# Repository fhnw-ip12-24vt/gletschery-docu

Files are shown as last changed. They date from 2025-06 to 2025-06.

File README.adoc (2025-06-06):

= Produktdokumentation Gletschery

== Einführung

Diese ReadMe-Datei dient als zentraler Steuerpunkt um Sie zu relevanten Informationen zum Produkt Gletschery zu führen.

Dazu gehören die Dokumentation von:

- Softwaredokumentation (SAD)
- Hardware-Dokumentation
- Testdokumentation
- Programmierkonventionen
- Anleitungen

== Softwaredokumentation (SAD)
Die link:software(sad)/sad/[Softwaredokumentation] ist nach den Vorgaben von arc42 erstellt worden (https://arc42.org/) und dokumentiert die Architektur der Softwarelösung.

Die link:software(sad)/system-idee.adoc[System-Idee] enthält das grundlegende Konzept des Projekts.
Es dient als ein Einstieg in die Soft- und Hardware-Dokumentationen.

== Hardwaredokumentation
In der link:hardware/HardwareDokumentation.adoc[Hardwaredokumentation] ist alles erfasst, was zum Bauen des Produkts nötig ist. Dazu gehören:

- *link:hardware/HardwareDokumentation.adoc#_teileliste[Teileliste]*: In der Teileliste sind alle Teile aufgeführt, welche im Produkt verbaut sind.
- *link:hardware/HardwareDokumentation.adoc#_files[Files]*: Beinhaltet alle Dateien, welche für die Erstellung von physischen Bauteilen aus Holz (z.b. Laser) und Plastik (z.b. 3D-Druck) gebraucht wurden.
- *link:hardware/HardwareDokumentation.adoc#_abmessungen[Abmessungen]*: Die Masse für Elemente, welche sich nicht automatisiert herstellen liessen.

Ausserdem enthält die Dokumentation unter anderem Informationen zur link:hardware/HardwareDokumentation.adoc#_wartung[Wartung], link:hardware/HardwareDokumentation.adoc#_erweiterbarkeit[Erweiterbarkeit] und link:hardware/HardwareDokumentation.adoc#_inbetriebnahme[Inbetriebnahme] des Produktes.

== Testdokumentation
Die Testdokumentation zeigt auf, wie geprüft wurde, ob das Produkt den Vorgaben entspricht.

Im link:testing/Admin/Test-Cases-Prüfplan.adoc[Prüfplan] ist festgehalten, welche Vorgaben wie überprüft werden. Einige Vorgaben werden automatisch mit Unit-Test überprüft, andere mit manuellen Tests.

Die Datei link:testing/Admin/Test-Cases-Übersicht.adoc[Test Cases Übersicht] enthält eine Zusammenfassung der durchgeführten Tests.

In der Datei link:testing/Admin/Test-Cases-Namenskonvention.adoc[Namenskonvention] wird aufgeführt auf, welche Beschriftung für die einzelnen Test Cases verwendet wird.

== Programmierkonventionen
Die link:software(sad)/coding_conventions.adoc[Coding Conventions] geben vor, wie der Code geschrieben wird.

== Anleitungen
Die link:software(sad)/Deployment_Anleitung.adoc[Deployment Anleitung] beschreibt im Detail, wie das Deployment durchgeführt werden muss.

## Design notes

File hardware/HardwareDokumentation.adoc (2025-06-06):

= Dokumentation Hardware
:toc-title: Inhalt
:toc: right
:toclevels: 4

== Komponentenübersicht
Die Hardware von Gletschery besteht im Wesentlichen aus:

* den PUI-Elementen, mit welchen der Spieler interagiert,
** Memory-Karten
** Arcade Buttons
** Monitor
* der Elektronik, welche die Funktionalität herstellt,
** Spannungsversorgung
** Zentraleinheit (Raspberry Pi)
** Kamera
** Licht
** diverse Kleinteile
* dem Gehäuse, welches alle Bestandteile vereint
** Holz-Bauteile
** Plexiglasplatte
** Farbe
** diverse Kleinteile

== Teileliste
Die Teileliste führt alle verbauten Bestandteile der Hardware von Gletschery auf.
Sie ist nach den Hauptbestandteilen der Komponentenübersicht gegliedert und gibt Auskunft über die Bezeichnung und die für uns entstandenen Kosten der einzelnen Bauteile.

Für weitere Details zu den einzelnen Komponenten folgen Sie den Links auf die Komponenten.

=== PUI

|===
|Komponenten |Bezeichnung |Beschaffung |Kosten

| Memory-Karten (24x)
| Eigenfertigung
| 3D-Druck
| 0.-

| xref:Komponenten/Arcade-Buttons.adoc[Arcade Buttons (3x)]
| Arcade Push Button illuminated (purecrea)
| Einkauf
| 15.70

| xref:Komponenten/Monitor.adoc[Monitor]
| PM-14 (verbatim)
| Einkauf
| 79.-

|===

=== Elektronik

|===
|Komponenten |Bezeichnung |Beschaffung |Kosten

| xref:Komponenten/Netzteil.adoc[Netzteil]
| TXN 75-105 (Traco Power)
| FHNW
| 0.-

| Hauptschalter
| Hauptschalter
| FHNW
| 0.-

| zentrale Steuereinheit
| Pi 5 (Raspberry)
| FHNW
| 0.-

| Shield
| Shield auf 40-Pin Header Pi (FHNW)
| FHNW
| 0.-

| xref:Komponenten/Kamera.adoc[Kamera]
| Camera Module 3 Wide (Raspberry)
| Einkauf
| 45.70

| xref:Komponenten/Kamera-Kabel.adoc[Kamera-Kabel]
| RASP CAM FPC 50 CSI (Raspberry)
| Einkauf
| 8.70

| LED-Band
| 5V LED-Band
| FHNW
| 0.-

| xref:Komponenten/LED-Steuerung.adoc[LED-Steuerung]
| Output Expander EM-03 (Pixelblaze)
| FHNW
| 0.-

| diverse Kabel
| Custom Eigenfertigung
| FHNW
| 0.-

|===

=== Gehäuse

|===
|Komponenten |Bezeichnung |Beschaffung |Kosten

| Holzgehäuse
| Custom Eigenfertigung Holz-Bauteile
| FHNW / Einkauf
| 19.45

| Kamera-Halter
| Eigenfertigung
| 3D-Druck
| 0.-

| Spielfläche
| Plexiglasplatte
| Einkauf
| 11.95

| Farbe
| FS Premium Buntlack S012.04
| Einkauf
| 15.95

| diverse Kleinteile
| Schrauben, Stifte, Scharniere
| eigene Werkstatt
| 0.-

|===

Die Gesamtkosten dieser Teileliste belaufen sich auf 196.45 CHF.

Dabei ist zu beachten, dass viele Bauteile kostenfrei von der FHNW zur Verfügung gestellt wurden und ein 1:1 Nachbau mit identischen Komponenten die Kosten um einiges erhöhen würden.

== Anschlussschemata

Die Schemata zeigen eine Übersicht über das Gesamtsystem der Spannungsversorgung und Signalverbindungen.

Einzelheiten auf welchen Steckplätzen welche Kabel angeschlossen sind sind unter den jeweiligen Komponenten zu finden:

* xref:Komponenten/Arcade-Buttons.adoc[Arcade Buttons (3x)]
* xref:Komponenten/LED-Steuerung.adoc[LED-Steuerung]

=== Spannungsversorgung

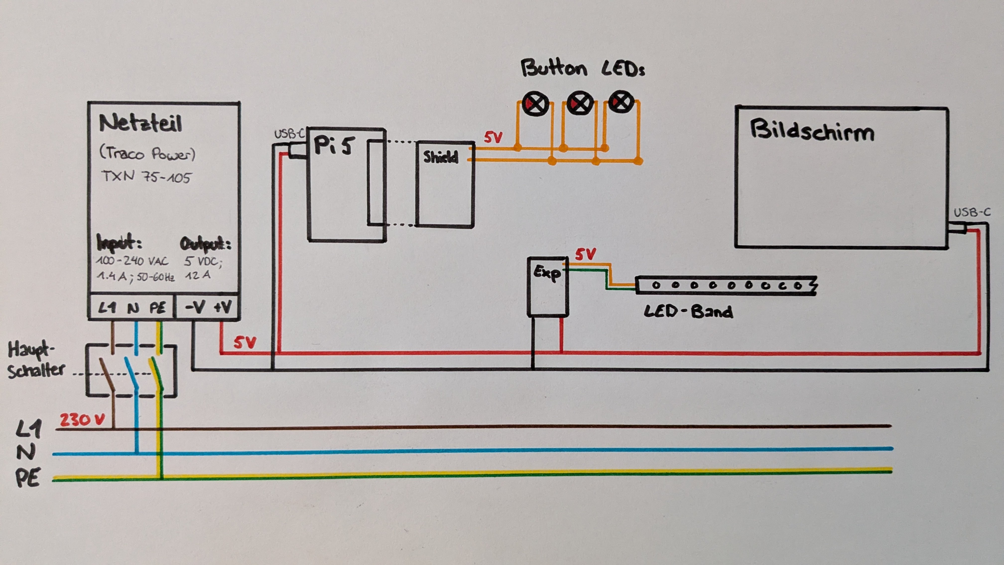
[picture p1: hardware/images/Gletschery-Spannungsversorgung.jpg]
ahhhhlternativtext


=== Signalverbindungen

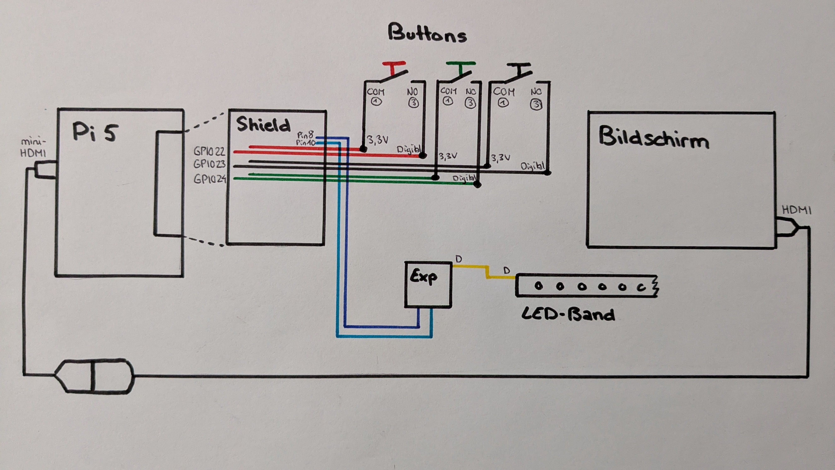
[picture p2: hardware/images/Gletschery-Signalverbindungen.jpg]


== Files

=== STP - Gletschery Modell

* xref:3D-Files/GletscheryModell.step[GletscheryModell.step]
* Pfad: hardware/Files/GletscheryModell.step
* Das GletscheryModell im STEP Format beinhaltet alle Bauteile des Gehäuses

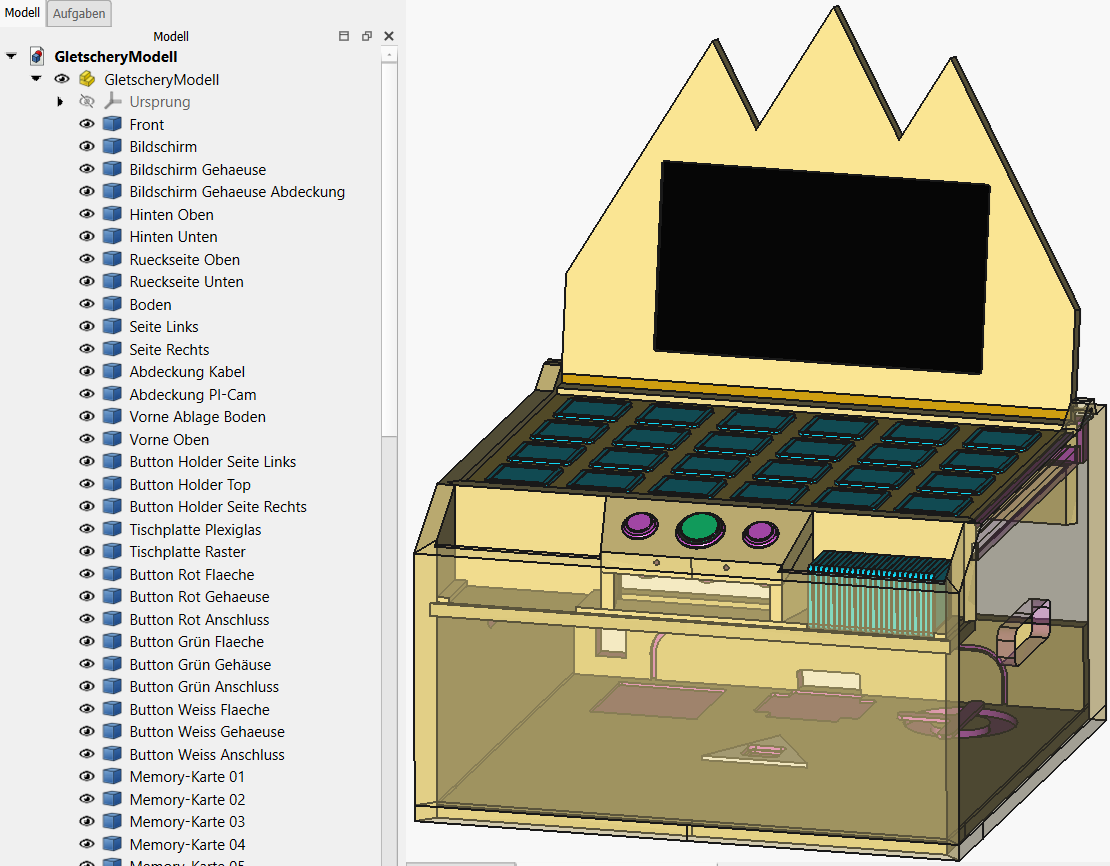
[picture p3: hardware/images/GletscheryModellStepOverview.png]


* Sollten Sie kein Programm haben um STP-/STEP-Dateien zu öffnen, empfehlen wir FreeCAD, ein kostenloses Open-Source CAD: https://www.freecad.org/
* Durch hovern über die Bauteile werden einzelne Komponenten hervorgehoben:

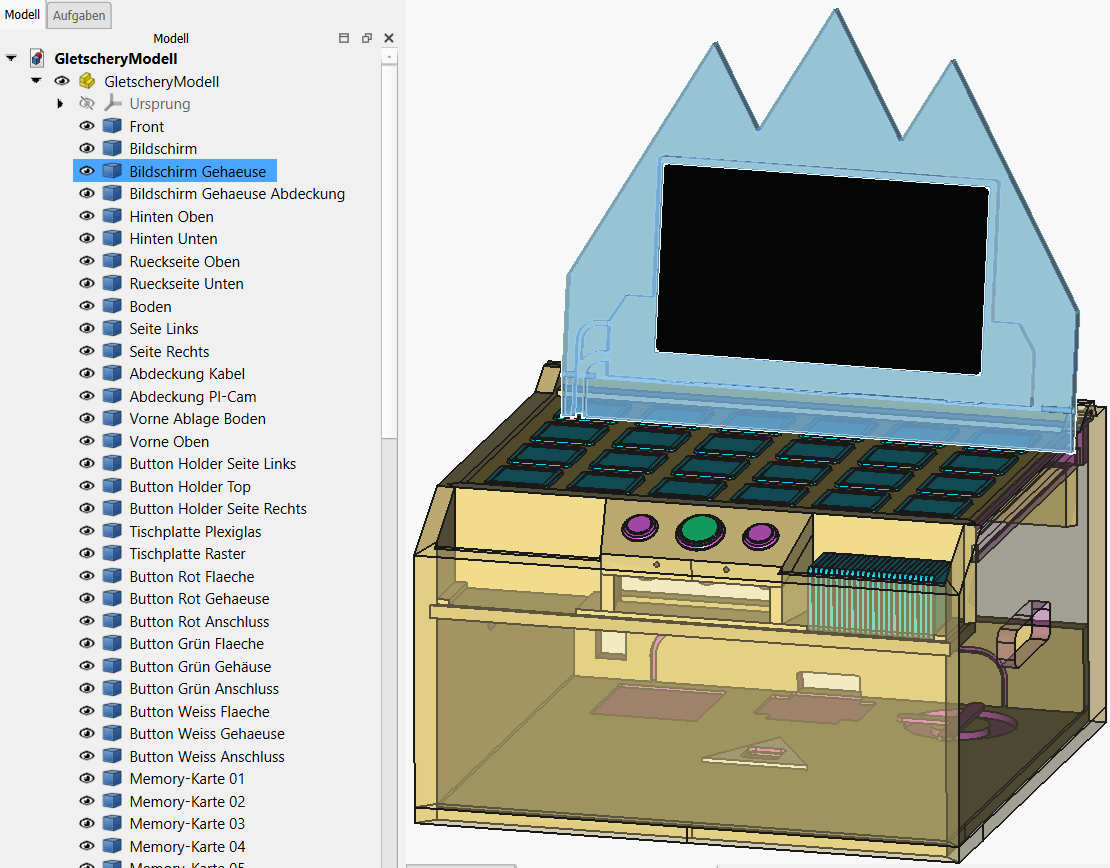
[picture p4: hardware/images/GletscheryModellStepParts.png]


[#_stl__3d_druck_modelle]
=== STL - 3D Druck Modelle

* Alle 3D-Druckmodelle wurden mit einem Original Prusa MK3.9 0.4 nozzle Drucker hergestellt
* Als Filament wurde Generic PLA hellblau verwendet
* Als Referenz für weitere Druckeinstellungen dient das folgende PrusaSlicer Projekt:
** xref:3D-Files/memory-cards-v5.3mf[memory-cards-v5.3mf]
** Pfad: hardware/Files/memory-cards-v5.3mf

==== Memory-Karten

* xref:3D-Files/memory-cards-v4 60x60x5_R5.stl[memory-cards-v4 60x60x5_R5.stl]
* Pfad: hardware/Files/memory-cards-v4 60x60x5_R5.stl

==== Kamera-Aufnahme

* xref:3D-Files/PI-CamHolderV2.stl[PI-CamHolderV2.stl]
* Pfad: hardware/Files/PI-CamHolderV2.stl

=== Abmessungen

* Aussenabmessungen Gletschery geöffnet: 519 x 500 x 656
* Aussenabmessungen Gletschery geschlossen: 519 x 500 x 317

Alle Masse in mm.

Bei Bedarf können die Masse jedes beliebigen Bauteils aus der STEP-Datei xref:3D-Files/GletscheryModell.step[GletscheryModell.step] in einem beliebigen CAD ausgelesen werden.

== Inbetriebnahme

Nach dem initialen Deployment der Software auf dem Raspberry Pi inklusive Autostart (welches vom Projektteam übernommen wird) ist die Inbetriebnahme des Produktes ganz einfach:

Schritte für die Inbetriebnahme:

* Anschliessen Stromkabel an Netz
** öffnen Sie die Rückseite des Gehäuses (durch öffnen der zwei Scharniere) und entnehmen Sie das mitgelieferte lose Stromkabel
** Stecken Sie das Stromkabel an der Rückseite (rechts unten) an und verbinden Sie die andere Seite mit Ihrem Stromnetz.
* Betätigen Sie den Hauptschalter
** Der Hauptschalter befindet sich gleich über dem Anschluss des Stromkabels welches Sie gerade verbunden haben
* Autostart
** Der Bildschirm startet sich nach einschalten des Stroms automatisch.
** Der Pi fährt sich ebenfalls automatisch hoch und startet das Spiel.
* Willkommen im Hauptmenü
** Nach einer kurzen Ladephase landen Sie bequem im Hauptmenü des Spiels, von wo aus Sie verschiedene Möglichkeiten haben:
*** ein neues Spiel starten
*** Sprache auswählen
*** Spielanleitung betrachten
*** eine Diashow der verwendeten Fotos ansehen
*** Die Credits lesen

Abschalten des Systems:

* Das System kann einfach über den Hauptschalter abgeschaltet werden

== Wartung

[#_plexiglas_auswechseln]
=== Plexiglas auswechseln

Das Plexiglas kann zur Rückseite hin herausgezogen werden.Im aufgestellten Zustand sind jedoch das Bildschirmgehäuse und deren Verkabelung im Weg.

Folgende vorbereitenden Schritte sind notwendig um das Plexiglas auszuwechseln:

* Zuklappen des Bildschirmgehäuses
* 3 Schrauben auf der Rückseite des Bildschirmgehäuses lösen, sodass die Abdeckung abgenommen werden kann.
* Strom- und HDMI-Kabel am Bildschirm entfernen und beachten, dass diese unterhalb der Nut für das Glas liegen.
* Um besseren Zugang zu haben wird empfohlen, das gesamte Oberteil abzunehmen: dazu entfernen Sie die beiden Stifte auf den Seiten (am Bestem mittels Kneif- oder Gripzange), danach kann das Oberteil einfach abgenommen werden.
* Entfernen Sie nun alle Karten sowie das Raster von der Spielfläche

Folgende Schritte werden zum Auswechseln empfohlen:

* Tragen Sie Sicherheitshandschuhe
* Öffnen Sie die Rückklappe und greifen sie mit einer Hand hindurch um die Plexiglasplatte von unten (nahe den Buttons) etwas in Richtung der Rückseite zu ziehen.
* Greifen Sie das Glas von oben mittig am entstandenen Spalt und drücken Sie es gleichmässig zur Rückseite hinaus
* Sobald das Glas über die Rückseite herausragt, ziehen Sie es von hinten hinaus.

Einschieben des neuen Glases

* Tipp: Schutzfolie nur an den Rändern etwas entfernen, sodass die Fläche beim Einschieben geschützt bleibt.
* Von der Rückseite her das Glas gleichmässig einschieben
* Wenn das Glas an der Vorderseite ansteht, durch die Rückklappe von unten mit einer Hand etwas anheben und mit der anderen Druck von Hinten geben, bis es schön in der Nut sitzt.
* Das Glas sitzt korrekt, sobald es auf der Rückseite vollständig bündig mit der Abdeckung ist.

Oberteil wieder anbringen:

* Legen Sie das Oberteil flach in Position
* Schieben Sie einen Stift von der Seite ein (durch leichtes Bewegen des Oberteils merken Sie, wann der Stift gefasst hat)
* Setzen Sie den Stift auf der gegenüberliegenden Seite
* Das Oberteil ist nun wieder befestigt
* Schliessen Sie Strom- und HDMI-Kabel an und legen Sie die Kabel in die entsprechenden Kanäle
* Schrauben Sie die Abdeckung wieder an.

=== Memory-Karten

Die Memory-Karten bestehen aus einem 3D gedruckten Körper, einem Gletscherfoto auf einer Seite und einem (dem Foto zugeordneten) QR-Code auf der anderen Seite.

Die Fotos/QR-Codes sind auf normales Papier gedruckt, laminiert und mit einem starken doppelseitigen Klebeband auf den Kartenkörper geklebt.

==== Karten-Körper

Es werden 8 Ersatzkarten mitgeliefert. Um selbständig Karten zu drucken, finden Sie weiter oben in diesem Dokument einige Infos, STL-Files sowie ein Druckprojekt, welches Sie verwenden können ->
xref:HardwareDokumentation.adoc#_stl__3d_druck_modelle[STL Modelle]

==== Gletscher-Fotos

Diese Doku beinhaltet 2 PDFs mit druckfertigen Fotos in der richtigen Grösse für die Karten. Einmal mit und einmal ohne Namen. Sollten Sie Anpassungen machen wollen, können Sie gerne das .docx als Vorlage nehmen:

* xref:Documents/eigene/All-Gletscher-Images 46mm.pdf[]
* xref:Documents/eigene/All-Gletscher-Images 46mm mit Label.pdf[]
* xref:Documents/eigene/All-Gletscher-Images 46mm.docx[]

==== QR-Codes

Druckfertige QR-Codes in der richtigen Grösse finden Sie in folgenden Dokumenten:

* xref:Documents/eigene/All-QR-Codes Table 42mm.pdf[]
* xref:Documents/eigene/All-QR-Codes Table 42mm.docx[]

==== Zuordnung

Die Zuordnung der Codes zu den Gletschern, sowie den angezeigten Texten findet in einem JSON-File statt. Infos dazu finden Sie in der

* xref:../software(sad)/Deployment_Anleitung.adoc#_daten[Deployment Anleitung unter Daten]

Die standalone Texte mit den Fakten finden Sie ansonsten in folgenden Dokumenten:

* xref:Documents/eigene/Fakten Gletscher DE.docx[]
* xref:Documents/eigene/Fakten Gletscher EN.docx[]
* xref:Documents/eigene/Fakten Gletscher FR.docx[]

=== Arcade-Buttons

Sollten Sie die Buttons auswechseln müssen, so ist dies möglich, aber nicht ganz einfach :)

Details zu den Buttons (Link zum Händler und elektrische Anschlüsse) finden Sie hier: xref:Komponenten/Arcade-Buttons.adoc[Arcade-Buttons]

* Folgen Sie der Anleitung xref:HardwareDokumentation.adoc#_plexiglas_auswechseln[Plexiglas auswechseln] bis zu dem Schritt an welchem Sie das Glas entfernt haben, um besseren Zugang zu haben.
* Nun können sie die Unterseite des auszuwechselnden Buttons (dort wo die Kabel angeschlossen sind) ein wenig gegen den Uhrzeigersinn drehen (dabei brauchen Sie initial etwas mehr Kraft als Sie erwarten würden, Sie merken jedoch schnell wenn es sich löst)
** (das Unterteil wird, beim Zusammenbau, zuerst in einer L-Nut gerade nach oben zusammengesteckt und dann etwas im Uhrzeigersinn gedreht, wodurch die Komponenten zusammenhalten - diesen Schritt gilt es umgekehrt zu machen)
** Sollte sich der gesamte Button Drehen, so geben Sie von der Oberseite Gegen-Druck auf den schwarzen Rand (aber nicht auf die Druckfläche - dies verhindert ein Lösen!)
* Nun kann das Unterteil des Buttons gerade nach unten herausgezogen werden. Die Kabelschuhe wurden für den besseren Halt gelötet.
** Sollten Sie diesen Teil auswechseln müssen so muss das Lot gelöst werden
** Markieren Sie sich unbedingt die Kabel auf der Button-Seite bevor Sie diese lösen, sodass Sie beim Ersetzen wissen, welche Anschlüsse wohin kommen. Die Anschlüsse auf Seite Pi/Shield sind entsprechend beschriftet.
* Um den Button / Oberen Teil zu entfernen, lösen Sie die Plastik-Mutter auf der Innenseite (nach Entfernen des Unterteils)
** Danach können Sie den gesamten Button von unten am Plastikgewinde gerade nach oben herausdrücken
** (Das Plastikgewinde dient nur dem Anziehen der Mutter, das Gehäuse selbst ist keine Gewinde- sondern eine Durchgangsbohrung)

== Erweiterbarkeit

Ideen zur Weiterentwicklung / Ausbau:

=== Spielfläche

* Weitere Raster um Anzahl Memory-Karten zu lenken
* Oder Sie versuchen das Raster wegzulassen, um die Technik sichtbarer zu machen. (wir hatten ohne Raster begonnen uns jedoch wegen folgenden Problemen für eines entschieden)
** mehr Probleme mit dem Auto-Fokus der Kamera auf entfernte Decken-Elemente
** weniger zuverlässige Erkennung der QR-Codes bei schräg liegenden Karten

=== Beleuchtung

* Die verbauten LEDs sind individuell steuerbar und RGB fähig
** Sie können das Innere in verschiedenen Farben oder Leuchtsequenzen zu neuem Leben erwecken
** Wir hatten beispielsweise während einiger Zeit bei einem richtigen Paar grün und bei einem falschen Paar oder Scan-Misserfolg rot angezeigt was richtig gut aussah (später jedoch wieder weggelassen, wir die Bildnachbearbeitung auf helles weisses Licht optimiert hatten)

=== Inhalt

* Auswechseln von Motiven und Texten ist ziemlich einfach in einem JSON-File möglich. Seien Sie kreativ.

=== Software

* Wie wäre es mit weiteren Spielmodi: zB einem Singleplayer oder Ranglisten-Modus

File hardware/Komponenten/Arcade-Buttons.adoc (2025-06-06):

= Arcade Buttons

|===
|Key specifications |details

|Hersteller
|purecrea

|Model
|Arcade Push Button Illuminated

|Spannungsversorgung LED
|5-12V

|Preis
|33mm: CHF 4.90; 45mm: 5.90

|Produktlink
|https://www.bastelgarage.ch/illuminated-arcade-button-33mm-red[Link zu 33mm Red auf bastelgarage.ch]

https://www.bastelgarage.ch/components/switch-button/arcade-push-button-illuminated-33mm-white[Link zu 33mm White auf bastelgarage.ch]

https://www.bastelgarage.ch/components/switch-button/arcade-push-button-lit-45mm-green[Link zu 45mm Green auf bastelgarage.ch]
|===

== Anschlüsse Signalverbindungen

image::../images/Arcade Buttons Signal Anschluesse.png[]

== Anschlüsse Stromversorgung

Die LED's der Buttons haben einen eigenen Stromkreis. Sie wurden von uns so zusammengebaut, dass der Anschluss auf der roten Seite dem 5V+, derjenige auf der schwarzen Seite dem 5V- auf dem Netzteil entspricht

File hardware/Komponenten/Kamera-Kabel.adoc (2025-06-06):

= Kamera-Kabel

|===
|Key specifications |details

|Model
|RASP CAM FPC 50

|connectors
|1x CSI - 1x CSI

|Length
|50mm

|Preis
|CHF 8.70

|Produktlink
|https://www.digitec.ch/en/s1/product/raspberry-pi-rasp-cam-fpc-50-raspberry-pi-camera-cable-1x-csi-1x-csi-050-m-development-board-accesso-40089192[Link zu Produkt auf digitec.ch]
|===

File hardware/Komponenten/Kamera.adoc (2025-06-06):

= Kamera

|===
|Key specifications |details

|Model
|Camera Module 3 Wide

|Sensor
|Sony IMX708

|Resolution
|11.9 megapixels

|Horizontal/vertical
|4608 × 2592 pixels

|Output
|RAW10

|Autofocus system
|Phase Detection Autofocus

|Cable connector
|15 × 1mm FPC

|Compliance
|FCC 47 CFR Part 15, Subpart B, Class B Digital Device
Electromagnetic Compatibility Directive (EMC) 2014/30/EU
Restriction of Hazardous Substances (RoHS) Directive
2011/65/EU

|Preis
|CHF 45.70

|weitere Dokumente
|xref:../Documents/camera-module-3-product-brief.pdf[Pi cameras product brief]

|Produktlink
|https://www.digitec.ch/en/s1/product/raspberry-pi-camera-module-3-wide-angle-120-development-board-accessories-24041966[Link zu Produkt auf digitec.ch]
|===

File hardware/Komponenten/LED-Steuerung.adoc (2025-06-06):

= LED-Steuerung

|===
|Key specifications |details

| Hersteller
| Pixelblaze

|Model
|Output Expander EM-03

|weitere Dokumente
|https://electromage.com/docs/output-expander[Output Expander Documentation]

|Produktlink
|https://shop.electromage.com/products/pixelblaze-output-expander-serial-to-8x-ws2812-apa102-driver[Link zum Produkt des Herstellers]
|===

Der Output Expander ist für die Steuerung und Spannungsversorgung des LED-Bands zuständig.

* Die Inputs 5V und GND sind direkt am Netzteil angeschlossen.
* Die Inputs DAT und CLK sind mit den GPIO-Pins 8 und 10 des Pi verbunden.
* Die Outputs 5V, GND und Data sind auf Reihe 0 mit den entsprechenden, gleich bezeichneten, Counter-Parts am LED-Band verbunden.

== Anschlüsse

image::../images/LED-Steuerung Anschluesse.jpg[]

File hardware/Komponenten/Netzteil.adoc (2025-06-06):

= Netzteil

|===
|Key specifications |details

| Hersteller
| Traco Power

|Model
|TXN 75-105

|Input
|100 - 240 VAC; 50/60 HZ

|Output
|5 VDC;

|weitere Dokumente
|xref:../Documents/txn75_datasheet.pdf[Technical data sheet]

|Produktlink
|https://www.tracopower.com/model/txn-75-105[Link zum Produkt des Herstellers]
|===

Das Netzteil versorgt unser gesamtes System mit Spannung.

Direkt an das Netzteil angeschlossen und mit 5V DC-Spannung versorgt werden:

* der Raspberry Pi
* der Bildschirm
* das LED-Band

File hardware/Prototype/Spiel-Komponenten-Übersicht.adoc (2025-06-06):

= Dokumentation Spiel-Komponenten

*Inhalt Spiel-Komponenten*

- [x] 1.1 Tisch
- [x] 2.1 Memory-Karten

'''
== 1.1 Tisch

Prototyp Komponenten:

|===
|Komponenten |Beschreibung

|xref:Tisch/MDF-Box.adoc[MDF-Box]

11.12.2024

|Prototype-Box welche Tischplatte sowie alle Hardware-Komponenten aufnehmen kann.

|xref:Tisch/Tischplatte.adoc[Tischplatte]

12.12.2024

|Durchsichtiges Spielfeld aus Glas oder Plexiglas.

|xref:Tisch/PiCam-Halterung.adoc[PI-CamHolder-v1]

17.12.2024

|Element, welches auf dem "Boden" der Prototyp-Box befestigt wird, um die PI-Kamera zu positionieren und befestigen.

|Steckerleiste
|Dient dem Stromanschluss von Pi, Monitor und LEDs

|LED-Band
|Dient der Beleuchtung des Innenraums der Box

|===

== 2.1 Memory-Karten

Tests/Prototypes:

|===
|Testlauf |Abklärung

|xref:MemoryCards/Memory-Cards-v1.adoc[Memory-Karten Test 1]

25.11.2024

|Abklärungen 3D-Konstruktion und 3D-Druck

|xref:MemoryCards/Memory-Cards-v2.adoc[Memory-Karten Test 2]

26.11.2024

|Ausprobieren verschiedener Formen und Grössen für UX-Testing

|xref:MemoryCards/Memory-Cards-v3.adoc[Memory-Karten Test 3]

27.11.2024

|Analyse & Verbesserung der Druckqualität und verschiedene Kartendicken für UX-Testing

|xref:MemoryCards/Memory-Cards-v4.adoc[Memory-Karten Test 4]

29.11.2024

|Verschiedene Formen in gleicher Druckqualität zur besseren Vergleichbarkeit. Genug in der Anzahl um für Prototype im Spiel zu verwenden.

|===

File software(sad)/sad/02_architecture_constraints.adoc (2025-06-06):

[[section-architecture-constraints]]
== Randbedingungen
=== Technische Einschränkungen
.Performance
Raspberry-Pi bietet eine limitierte Performance, welche bei der Entwicklung und Umsetzung beachtet werden muss. Zudem läuft auf dem Raspberry-Pi eine Linux Distribution, was bei der Umsetzung ebenso beachtet werden muss, da dies bei Aspekten wie Pfade von Ressourcen (z.B. Bildern) wichtig ist.

.Lichtverhältnisse
Dadurch, dass unser Produkt mit einer Kamera arbeitet, welche von unten QR-Codes scannt, können die Lichtverhältnisse im Raum und in der Box zu  Problemen führen. Sollte zu viel oder zu wenig Licht auf die Kameralinse treffen, kann dies zur schlechten Erkennung von QR-Codes führen.

.QR-Code Erkennung
Neben schlechten Lichtverhältnissen können weitere Faktoren, wie beispielsweise der Zustand der Memorykarten, die Erkennung des QR-Codes beeinflussen.

.Java
Ebenfalls wurde von der Programmleitung festgelegt, dass Java als Programmiersprache verwendet werden muss.

==== Git-Versionierung
Die Versionierung der Dokumentation und des Codes erfolgt gemäss den Vorgaben der Projektleitung mit Git und GitLab.

.Richtlinien
Damit die Dokumentation und der Code stets übersichtlich bleibt, werden Richtlinien festgelegt, die von den Teammitgliedern befolgt werden.

.Namenskonvention
Um die Übersicht zu behalten, welcher Branch wofür erstellt wurde, wurde eine Namenkonvention definiert, nach welcher gearbeitet wird.

- **Code-Repository**
** Name des Branches: "Feature-[NAME]"
-> (z.B. Feature-Scanner)
- **Dokumentation**
** Name des Branches: [Rolle] -> (z.B. software-architect)

.Erklärung
Für jede Änderung im Code oder in der Dokumentation wird ein neuer Branch erstellt, der den definierten Namenskonventionen entspricht. Nach der Bearbeitung wird der Branch-Stand gepusht und schliesslich mit dem Main-Branch zusammengeführt. Der verwendete Branch wird nach dem Zusammenführen gelöscht.

Im Gegensatz zur Code-Dokumentation wird das Mergen von Code im Code-Repository mit dem Main-Branch von anderen Teammitgliedern überprüft. Dies dient dazu, potenzielle Gefährdungen des bestehenden Codes und den damit verbundenen Aufwand zur Behebung von Problemen zu vermeiden. Die Überprüfung des Codes erfolgt durch den Software Developer oder Software Architect des Teams.

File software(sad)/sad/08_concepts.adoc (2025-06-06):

[[section-concepts]]
== Querschnittliche Konzepte
=== Fachliche Konzepte

==== Bewusstseinsbildung
Das Spiel dient nicht nur der Unterhaltung, sondern verfolgt ein pädagogisches Ziel: Die Vermittlung von Wissen über Gletscher, deren Rückgang und die klimatischen Zusammenhänge. Dieses Ziel ist systemweit relevant und beeinflusst die inhaltliche Gestaltung der Karten, die Auswahl der Bilder sowie die Textbausteine der GUI.

==== Memory
Das Spiel basiert auf dem bekannten Memory-Prinzip. Zwei Karten mit gleichem Bild oder thematischem Zusammenhang müssen gefunden werden. Eine Übereinstimmung triggert die Anzeige weiterführender Informationen auf dem Bildschirm. Diese Spielmechanik bildet das Grundmodell für alle Interaktionen.

=== User Experience (UX)

==== Feedback-Verhalten
Spielrückmeldungen erfolgen multimodal:

* Visuell über Display (Text und Farbwechsel)
* Namen der Gletscher und Bilder auf den physischen Karten

==== Barrierefreiheit
Das Spiel ist für Jugendliche ab 13 Jahren konzipiert. Farben und Kontraste wurden für gute Lesbarkeit gewählt. Steuerung erfolgt hardwareseitig über drei klar gekennzeichnete Tasten (Farbcodierung: Rot, Grün, Weiss).

==== Steuerung
Alle Spielaktionen werden über drei physische Buttons ausgelöst:

* Rot = Spiel beenden / zurück
* Grün = Bestätigen / Scannen
* Weiss = Navigation

Die Knöpfe sind bewusst mechanisch um einfache Bedienung zu garantieren.

=== Sicherheitskonzepte

==== Scan-Bildverarbeitung
Bilder von der Kamera werden lokal und flüchtig verarbeitet:

* Es erfolgt zwar eine Speicherung von Bilddaten, diese werden aber überschrieben und nach dem Beenden einer Runde gelöscht.
* Verarbeitung direkt bei Erstellung, via FFMPEG.
* Nur extrahierter QR-Text wird weiterverarbeitet.

==== Hardwareschutz
* Das System ist vollständig in einer verschlossenen Holzkiste untergebracht.

=== Architektur- und Entwurfsmuster

==== MVC
Die Java-Anwendung folgt der **MVC** Architektur

* **Model**: Spielzustand, Kartendaten
* **View**: Anzeige auf dem Bildschirm
* **Controller**: Programm logik

==== Threads und zusätzliche Prozesse
Die Anwendung ist multi-threaded:

* **Thread 1**: Gletschery Game-Loop an sich (dauerhaft aktiv)
* **Thread 2**: Scannen und Lesen nach QR-Codes(nur während Spiel aktiv)
* **Prozess**: Zusätzlich wird ein Bash-Script ausgeführt welches jede Sekunde ein neues aktuelles Foto abspeichert.

=== Unter der Haube

==== GPIO und UART
* Drei Buttons sind an dedizierte GPIO-Pins angeschlossen.
* Eine LED wird über den UART (seriell) angesteuert über vorgeschalteten Mikrocontroller.
* Alle GPIOs werden über PI4J verwaltet.

==== Kameraeinbindung
* Kamera: PiCam Modul 4, angebunden über CSI-Port
* Zugriff: Libcamera und FFMPEG in Java
* Verarbeitung: Live-Frame-Erfassung,
* Performance: 1 fps

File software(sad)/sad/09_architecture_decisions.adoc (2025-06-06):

[[section-design-decisions]]
== Architekturentscheidungen
=== MVC

Für unser Projekt wurde aus verschiedenen Gründen entschieden eine MVC Architektur zu verwenden.
Im Folgenden werden die wichtigsten Gründe erwähnt.

1. **Wartbarkeit:**
* Dadurch, dass unser Projekt notfalls von einer externen Partei gewartet werden muss, ist es von Vorteil, wenn die Komponenten so wenige Abhängigkeiten wie möglich voneinander haben.
2. **Separation of Concerns (Trennung von Verantwortlichkeiten):**
* Die Aufteilung der einzelnen Komponenten führen dazu, dass die einzelnen Komponenten getestet werden können, ohne die Logik zu beeinflussen.
3. **Testbarkeit:**
* Unit-Tests können für Models und Controller einfacher geschrieben werden.
4. **User-Interface:**
* Dadurch, dass unser Spiel verschiedene Screens haben wird, welche die gleichen Daten anzeigen, ist eine MVC Architektur von Vorteil.

=== Klassendiagramm

Um die Struktur des Codes festzulegen, wurde ein Klassendiagramm erstellt. **Jede Schicht der MVC Architektur wird in einem eigenen Package** zusammengefasst.
Der Grund dafür ist die Sicherstellung, dass **keine Schichten übergreifende Relationen** entstehen.

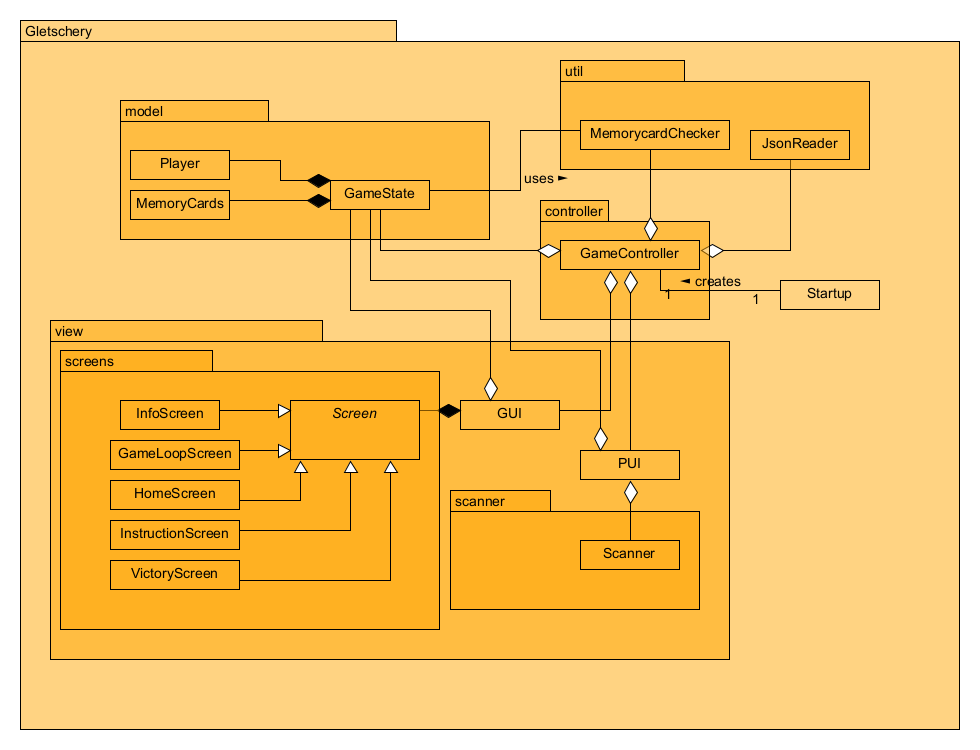
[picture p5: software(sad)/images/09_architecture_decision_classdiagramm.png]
Klassendiagramm


=== Architecture Decisions

[cols="1,3" options="header"]
|===
|Name |Decision
|Gletscherbilder Speicher Ort| Die Gletscherbilder werden auf dem Raspberry-PI unter "/home/pi/Pictures" gespeichert, um einfach austauschbar zu sein.
|Scan Image Speicher Ort| Das Scan-Image wird während des Spiels hier abgelegt "/home/pi/Pictures".
|Löschen des letzten Scan Images| Sobald das Spiel beendet wurde soll das letzte Bild gelöscht werden um gegen keine Datenschutzrichtlinien zu verstossen.
|Json speicher Location| Das Json wird auf dem Raspberry-PI unter "/home/pi/Documents" gespeichert.
|Json aufbau | Das Json ist wie folgt aufgebaut
|Karten ID's | Die IDs der Karten sind ein String, welcher so aufgebaut ist: <Paar-ID><CardIdentifier>. Als CardIdentifier wird jeweils A oder B verwendet. z.B. "00A"
|Paar-ID| Die Paar-ID besteht immer aus 2 Zeichen
|Paar-ID Start| Die Vergabe der ID's startet bei 00
|===

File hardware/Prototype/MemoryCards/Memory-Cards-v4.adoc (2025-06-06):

= Memory-Karten Test 4

*Datum:* Fr, 29.11.2024

*Testziel:*

- [x] Verschiedene Dicken und Formen für engere Auswahl UX-Tests
- [x] Analyse & Verbesserungspotenzial der Druckqualität

'''

*Testdetails:*

Konstruktion Details

- Grösse: 60x60
- Eckform: Fasen und verschiedene Radien
- je zwei verschiedene Dicken in 6mm und 5mm
- alle Karten haben oben und unten eine Vertiefung von 1 um Bild/QR-Code zu platzieren
- alle scharfen Aussenkanten haben eine Fase von 0.5
- Files: xref:3D_Files/memory-cards-v4 60x60x5_F5.stl[memory-cards-v4 60x60x5_F5.stl] ; xref:3D_Files/memory-cards-v4 60x60x5_R5.stl[memory-cards-v4 60x60x5_R5.stl] ; xref:3D_Files/memory-cards-v4 60x60x5_R6.stl[memory-cards-v4 60x60x5_R6.stl] ; xref:3D_Files/memory-cards-v4 60x60x5_R7.stl[memory-cards-v4 60x60x5_R7.stl] ; xref:3D_Files/memory-cards-v4 60x60x6_F5.stl[memory-cards-v4 60x60x6_F5.stl] ; xref:3D_Files/memory-cards-v4 60x60x6_R5.stl[memory-cards-v4 60x60x6_R5.stl] ; xref:3D_Files/memory-cards-v4 60x60x6_R6.stl[memory-cards-v4 60x60x6_R6.stl] ; xref:3D_Files/memory-cards-v4 60x60x6_R7.stl[memory-cards-v4 60x60x6_R7.stl]

3D-Druck Details

- Anzahl Karten: 8
- Grössen: 60x60x6 und 60x60x5
- Druckeinstellungen: Voreinstellungen modifiziert: PLA; 0.4 Nozzle; 0.2 Speed; glattePlatte; Perimeter: 10mm; Deckenfüllmuster: Ausgerichtet Geradlinig; Randbreite: 3mm; Infill: 15%, Füllmuster: Gitternetz; generiere Stützmaterial + Stützen automatische generieren;

'''

*Ergebnis:*

- Oberfläche Rand mit neuer Strategie (Perimeter 10mm) nicht so glatt wie mit alter Strategie, dafür gleichmässiger. An einigen Ecken sind Bahnen etwas auseinandergezogen.
- Tiefere Aussparung auf Ober- und Unterseite gut gelungen
- Zusammen mit Test 1, 2 und 3 haben wir nun viele verschiedene Formen und Grössen um Userfeedback einzuholen um das Kartendesign zu finalisieren
- Wir haben nun genug gedruckte Karten um ein Testspiel mit halbem Umfang zu machen (12 Memory Karten, 6 Paare)

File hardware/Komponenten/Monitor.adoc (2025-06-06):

= Monitor

|===
|Key specifications |details

|Model
|Verbatim PM-14

|Monitor type
|PC Monitor, Portable Monitor

|Display size
|14"

|Display resolution
|1920x1080

|Screen technologie
|LCD

|Refresh rate
|60 Hz

|Video connections
|HDMI (1x)

|USB ports
|USB-A, USB-C

|Monitor equipment
|Integrated loudspeakers, Integrated USB hub

|Preis
|CHF 79.- (Aktion)

|weitere Dokumente
|xref:../Documents/Produktdatenblatt PM-14.pdf[Technical data sheet]

|Produktlink
|https://www.digitec.ch/en/s1/product/verbatim-pm-14-1920-x-1080-pixels-14-monitor-24552684?tagIds=77-624[Link zu Produkt auf digitec.ch]
|===

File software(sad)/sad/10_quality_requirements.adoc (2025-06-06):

[[section-quality-scenarios]]
== Qualitätsanforderungen
.Einleitung
Diese Anforderungen dienen als Grundlage für die Architektur und unterstützen dabei, die Erwartungen der Stakeholder klar zu erfassen und gezielt umzusetzen.

=== Qualitätsbaum
Der Qualitätsbaum stellt alle Qualitätsanforderungen unseres Produktes übersichtlich dar. Wir haben uns dabei vor allem auf die Qualitätsziele **Leistungseffizienz**, **Benutzerfreundlichkeit** und **Wartbarkeit** fokussiert. Diese Qualitätsziele basieren auf den Vorgaben und Anforderungen des Kunden Primeo Energie.

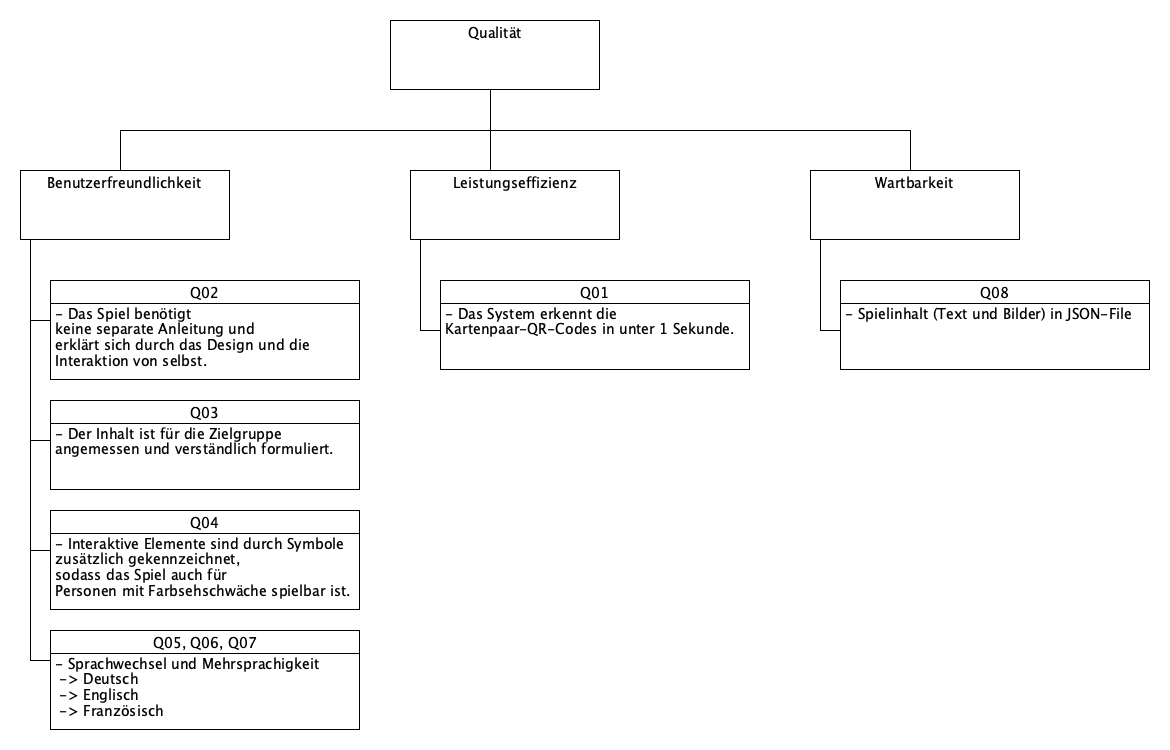
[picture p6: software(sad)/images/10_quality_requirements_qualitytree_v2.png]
Qualitätsbaum


=== Qualitätsanforderungen im Detail

[cols="1,2,4", options="header"]
|===
| Anforderung | Qualitätsanforderung | Beschreibung

| Q01
| Leistungseffizienz
| Das System erkennt die Kartenpaar-QR-Codes in unter 1 Sekunde.

| Q02
| Benutzerfreundlichkeit
| Das Spiel benötigt keine separate Anleitung und erklärt sich durch das Design und die Interaktion von selbst.

| Q03
| Benutzerfreundlichkeit
| Der Inhalt ist für die Zielgruppe angemessen und verständlich formuliert.

| Q04
| Benutzerfreundlichkeit
| Interaktive Elemente sind durch Symbole zusätzlich gekennzeichnet, sodass das Spiel auch für Personen mit Farbsehschwäche spielbar ist.

| Q05
| Benutzerfreundlichkeit
| Das Spiel ist in mehreren Sprachen verfügbar und kann vor dem Start des Spiels ausgewählt werden.

| Q06
| Benutzerfreundlichkeit
| Die Menüstruktur ist in allen Sprachen konsistent und übersichtlich.

| Q07
| Benutzerfreundlichkeit
| Alle Inhalte sind in den Sprachen Deutsch, Englisch und Französisch verfügbar.

| Q08
| Wartbarkeit
| Die Spielinhalte (Texte und Bilder) sind in einer externen JSON-Datei abgelegt und können ohne Änderung des Quellcodes angepasst werden.
|===

[.small]
-> *QS-01* prüft *Q01 (Leistungseffizienz)*

-> *QS-02* prüft *Q02 (Benutzerfreundlichkeit – selbsterklärende Bedienung)*

-> *QS-03* prüft *Q03 (Benutzerfreundlichkeit – Angemessenheit der Sprache im Spiel)*

-> *QS-04* prüft *Q04 (Benutzerfreundlichkeit – Barrierefreiheit)*

-> *QS-05* prüft *Q05 (Benutzerfreundlichkeit – Sprachwahl)*

-> *QS-06* prüft *Q06 (Benutzerfreundlichkeit – konsistente Menüstruktur)*

-> *QS-07* prüft *Q07 (Benutzerfreundlichkeit – Inhalte in mehreren Sprachen anzeigen)*

-> *QS-08* prüft *Q08 (Wartbarkeit – Anpassungen an der JSON-Datei)*

=== Qualitätsszenarien

[cols="1,2,2,2,2", options="header"]
|===
| ID | Stimulus | Umgebung | Reaktion des Systems | Erfolgskriterium

| QS-01
| Ein Spieler deckt eine Karte bei schwachen Lichtverhältnissen auf.
| Umgebungslicht ohne direkte Beleuchtung
| Das System erkennt den QR-Code innerhalb einer Sekunde.
| QR-Code wird in 95 % der Fälle korrekt erkannt

| QS-02
| Ein Benutzer startet das Spiel zum ersten Mal.
| Kein Vorwissen über Spiel oder Steuerung
| Der Spieler findet sich im Menü zurecht und startet das Spiel ohne Hilfe.
| 90 % der Testpersonen benötigen keine Erklärung

| QS-03
| Ein Spieler liest den Infotext über einen Gletscher im Spiel
| Spiel läuft in deutscher Sprache
| Die Texte sind altersgerecht und leicht verständlich formuliert.
| Mindestens 90 % der Testpersonen (entspricht 9 von 10) verstehen die Inhalte ohne Rückfragen.

| QS-04
| Ein farbenblinder Spieler nutzt das System.
| Spiel läuft im Normalbetrieb
| Alle interaktiven Elemente sind auch durch Symbole eindeutig erkennbar.
| Der Spieler kann ohne Probleme durch das Spiel navigieren.

| QS-05
| Eine Spielerin möchte das Spiel auf Französisch nutzen.
| Sprache im Startmenü auf Französisch gestellt
| Alle Menüs und Texte erscheinen in korrekter französischer Übersetzung.
| Keine fehlenden oder unübersetzten Texte sind zu sehen

| QS-06
| Ein Spieler wechselt zwischen Deutsch, Englisch und Französisch.
| Menüführung in den verschiedenen Sprachen (Deutsch, Englisch und Französisch) jeweils ausgewählt.
| Menüstruktur bleibt in allen Sprachen identisch aufgebaut.
| Kein Unterschied in Navigationsstruktur oder Position von Buttons

| QS-07
| Ein Schüler spielt das Spiel auf Englisch.
| Englische Sprache im Startmenü ausgewählt
| Alle Inhalte (Texte und Buttons) erscheinen korrekt übersetzt.
| Alle Inhalte erscheinen in der gewünschten Sprache

| QS-08
| Neue Inhalte (Bilder, Texte) sollen eingepflegt werden.
| Ein Entwickler aktualisiert die JSON-Datei mit neuen Inhalten.
| Die neuen Inhalte werden beim nächsten Spielstart korrekt angezeigt.
| Die Änderungen erfolgen ohne Codeanpassung und das Spiel startet fehlerfrei.
|===

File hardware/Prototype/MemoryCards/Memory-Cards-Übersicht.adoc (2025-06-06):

= Memory Card Übersicht

*Datum:* Mi, 05.03.2025

*Inhalt*

Diese Übersicht dient der Dokumentation der QR-Codes und ihrer eindeutigen Zuordnung zu einer bestimmten Memorykarte.

'''
*Zuweisung*

|===
|QR-Code |Bild |Pfad

|01A |XX |
|01B |XX |
|02A |XX |
|02B |XX |
|03A |XX |
|03B |XX |
|04A |XX |
|04B |XX |
|05A |XX |
|05B |XX |
|06A |XX |
|06B |XX |
|07A |XX |
|07B |XX |
|08A |XX |
|08B |XX |
|09A |XX |
|09B |XX |
|10A |XX |
|10B |XX |
|11A |XX |
|11B |XX |
|12A |XX |
|12B |XX |

|===

Die Identifikationsnummer der QR-Codes setzt sich aus einer einzigartigen Zahl und dem Buchstaben 'A' oder 'B' zusammen. Der Buchstabe kennzeichnet dabei das historische bzw. das neuzeitliche Bild des Kartenpaares.

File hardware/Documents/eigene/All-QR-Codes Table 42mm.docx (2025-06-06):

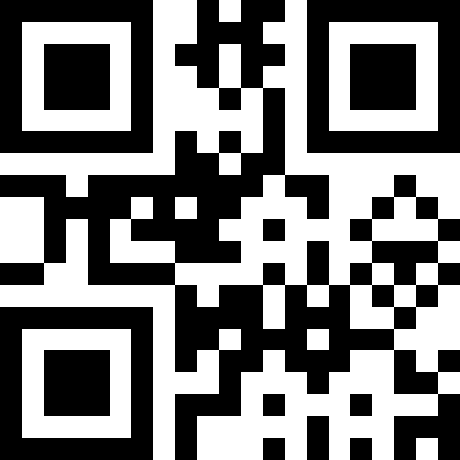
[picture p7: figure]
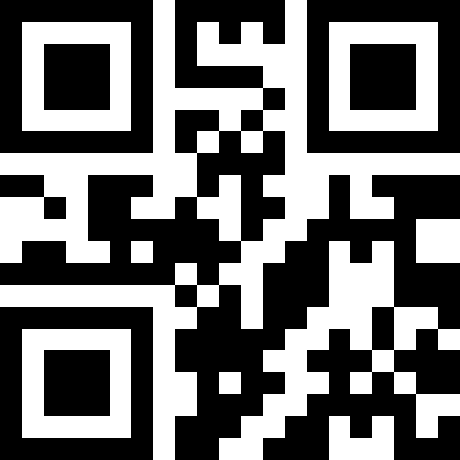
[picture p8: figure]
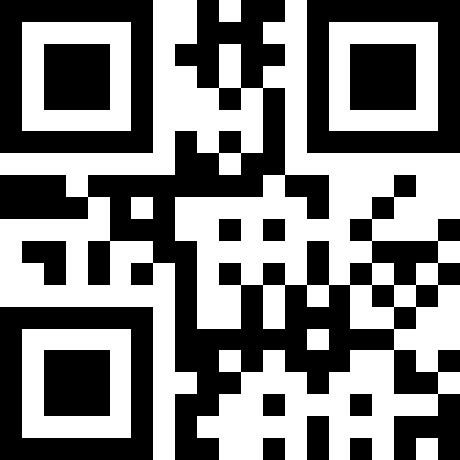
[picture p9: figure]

00A | 00B | 01A

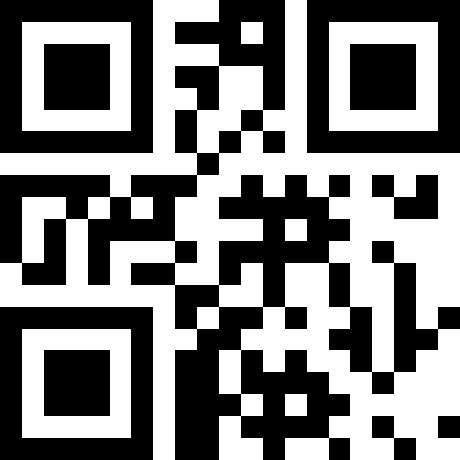
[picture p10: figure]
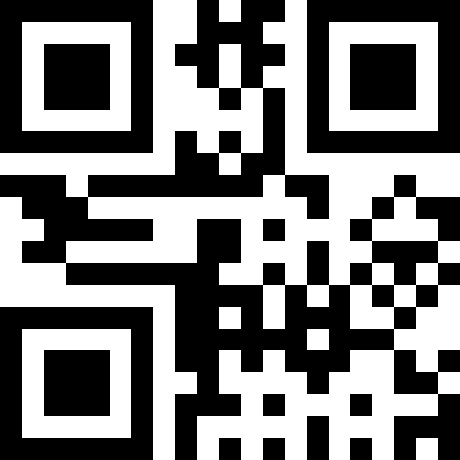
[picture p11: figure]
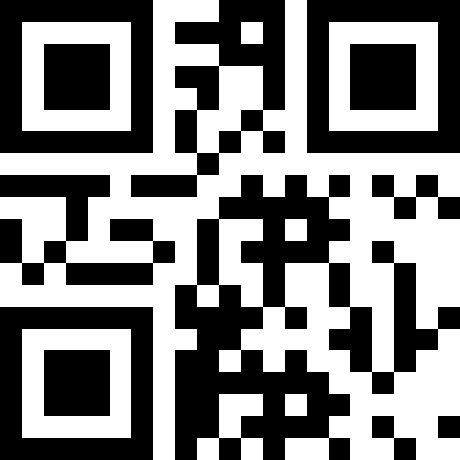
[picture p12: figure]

01B | 02A | 02B

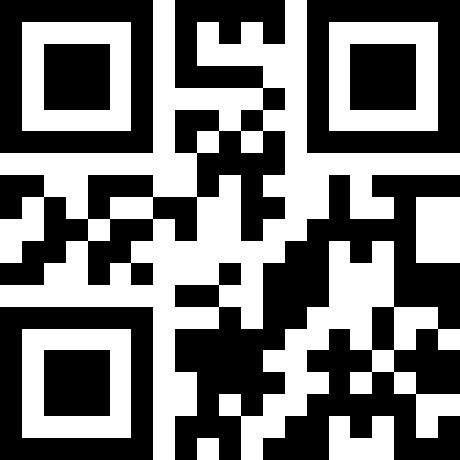
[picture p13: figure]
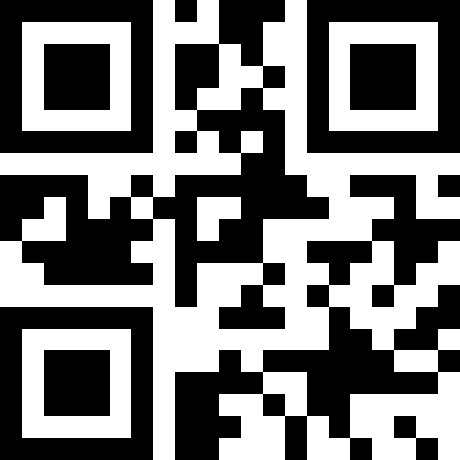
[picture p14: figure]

03A | 03B | 04A

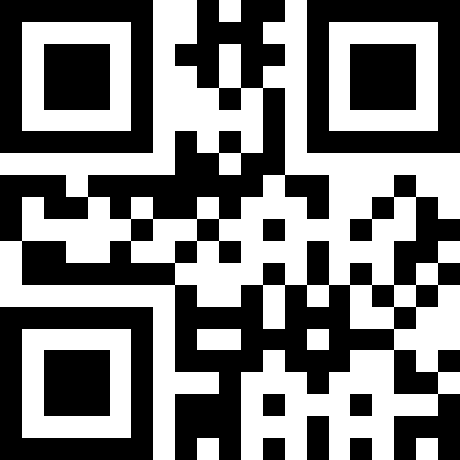
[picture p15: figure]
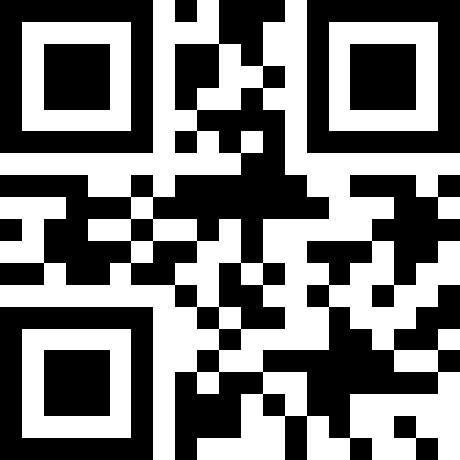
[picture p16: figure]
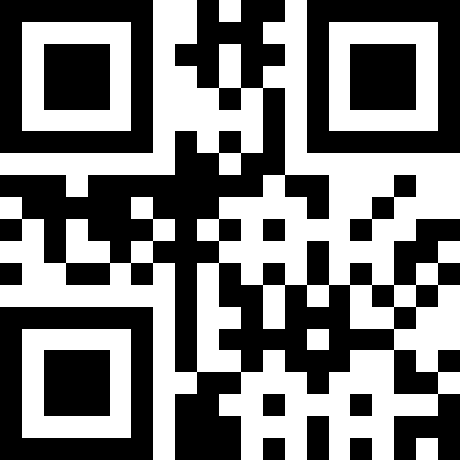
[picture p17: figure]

04B | 05A | 05B

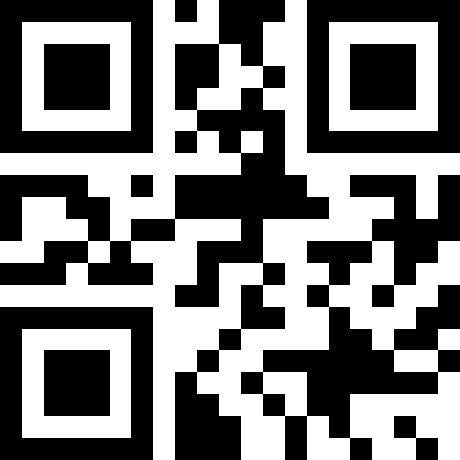
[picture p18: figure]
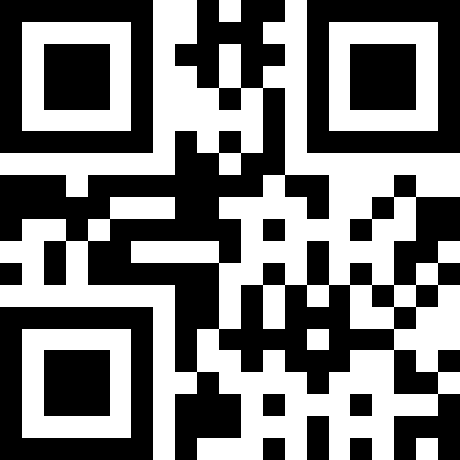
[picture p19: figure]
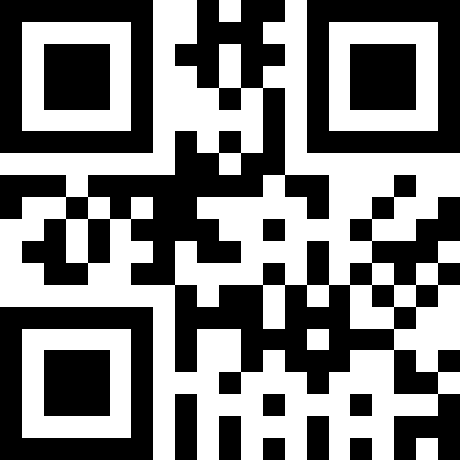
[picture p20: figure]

06A | 06B | 07A

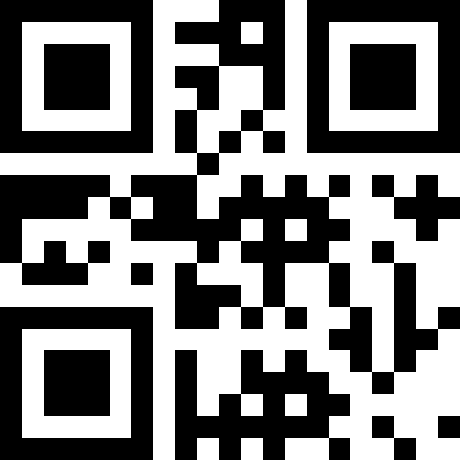
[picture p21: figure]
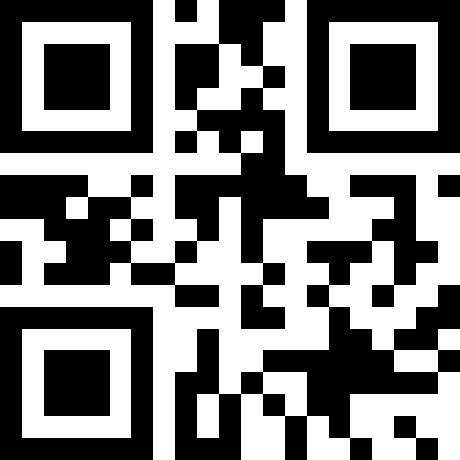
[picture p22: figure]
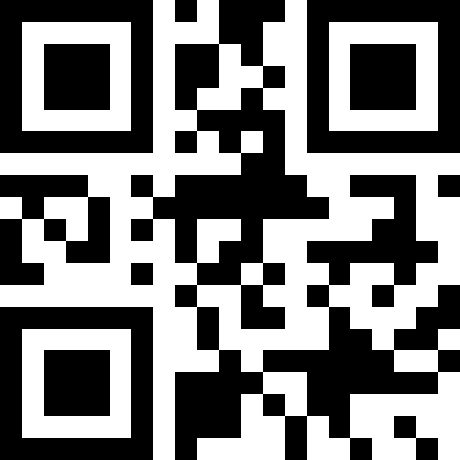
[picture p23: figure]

07B | 08A | 08B

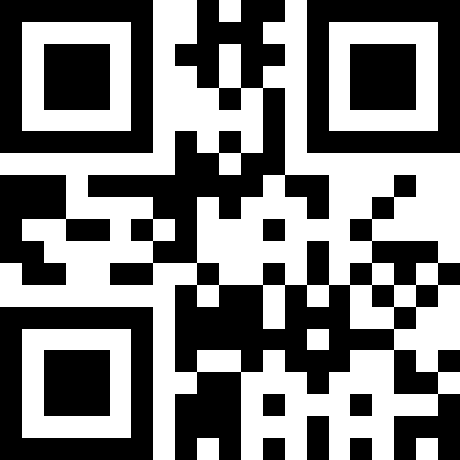
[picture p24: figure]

09A | 09B | 10A


10B | 11A | 11B


12A | 12B

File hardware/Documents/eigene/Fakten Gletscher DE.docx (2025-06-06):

Persgletscher, GR

Früher war der Gletscher fest mit dem Morteratschgletscher verbunden. Durch die Schmelze sind die beiden Gletscher momentan nicht mehr miteinander verbunden.

Tiefengletscher, UR

Der Tiefengletscher ist ein Talgletscher in den Urner Alpen. Das Schmelzwasser des Gletschers fliesst über den Sidelenbach in die Reuss, dann in die Aare, wo es schliesslich in den Rhein mündet.

Pizolgletscher, GR

Der Pizolgletscher zerfiel aufgrund der grossen Hitze im Jahr 2018 in mehrere, einzelne Teile. Er gilt als einer der ersten Schweizer Gletscher, der vollständig schmelzen wird.

Tschiervagletscher, GR

Der Tschiervagletscher war bis 1944 mit dem Roseggletscher im Tal Roseg verbunden. Der Rückzug beider Gletscher führte dann zur Bildung des "Lej da Vadret".

Gornergletscher, VS

Der Gornergletscher erstreckt sich über etwa 12 Kilometer, wobei er an seine dicksten Stellen eine Eisstärke von über 350 Meter erreicht. Seit 1850 ist er bereits über 3 km zurückgegangen.

Aletschgletscher, VS

Der grösste Gletscher der Alpen und doch sagen Prognosen voraus, dass er bis zum Ende 21. Jahrhundert fast komplett verschwinden könnte.

Riedgletscher, VS

Vor langer Zeit wurde das Wasser des Gletschers über alte Wasserleitungen namens «Suonen» bis zu den Gemeinden St. Nikolaus und Grächen transportiert, um dort die Wiesen zu bewässern.

Fieschergletscher, VS

Der Fieschergletscher ist mit 14 km einer der längsten Gletscher der Alpen und hat seit 1850 bereits über 3 km an Länge verloren.

Roseggletscher, GR

Durch das Schmelzen des Gletschers hat sich ein neuer Gletschersee gebildet, der weiterwächst, während das Eis schwindet.

Trientgletscher, VS

Aufgrund seiner Steile schmilzt der Gletscher schneller als andere, somit zeigt er früher als andere Gletscher, wie sich das Klima auf die Alpen auswirkt.

Rhonegletscher, VS

Seit einigen Jahren werden Teile des Gletschers mit weissem Fliessstoff abgedeckt, um die Schmelze zu verlangsamen.

Triftgletscher, BE

Durch die starke Schmelze hat sich in den 1990er der Triftsee gebildet und wächst seitdem jedes Jahr weiter an.


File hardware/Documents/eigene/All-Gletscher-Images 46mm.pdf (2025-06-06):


00A | 00B | 01A
01B | 02A | 02B
03A | 03B | 04A
04B | 05A | 05B


06A | 06B | 07A
07B | 08A | 08B
09A | 09B | 10A
10B | 11A | 11B

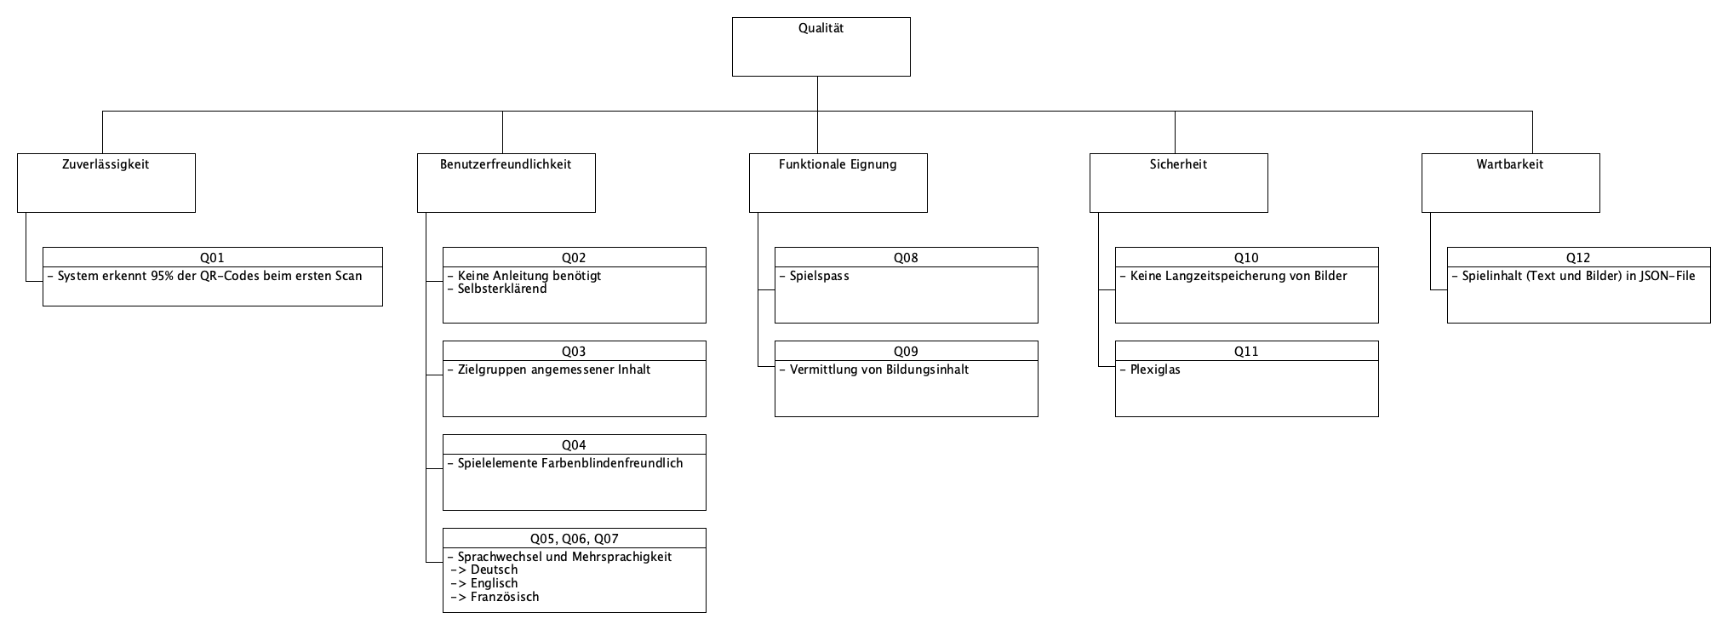
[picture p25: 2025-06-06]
software(sad)/images/10_quality_requirements_qualitytree.png

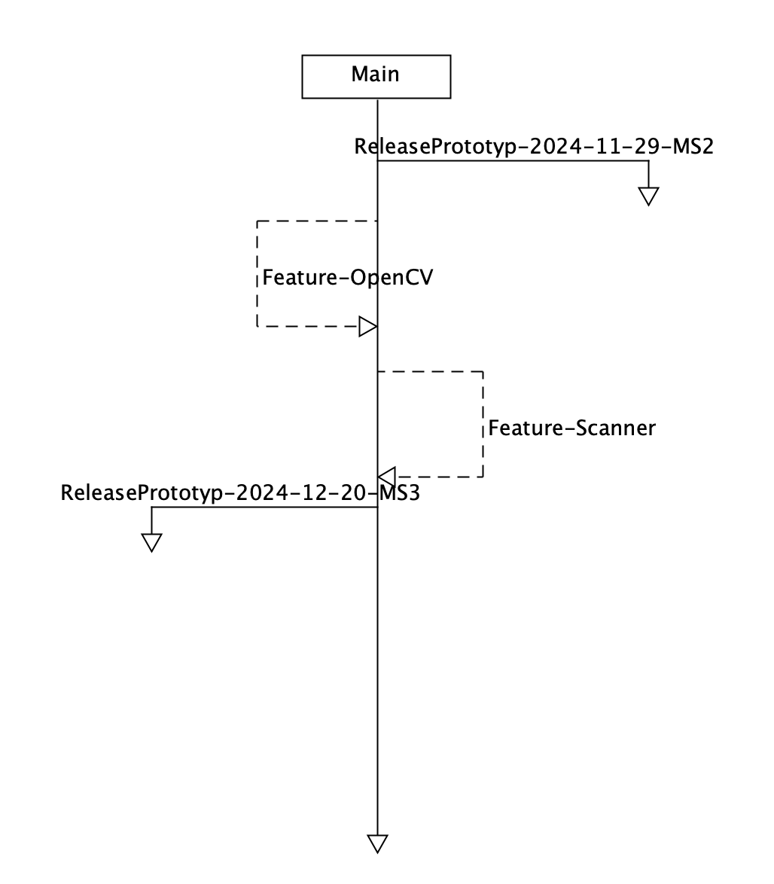
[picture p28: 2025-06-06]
software(sad)/images/02-architecture-constraints-git-branches.png

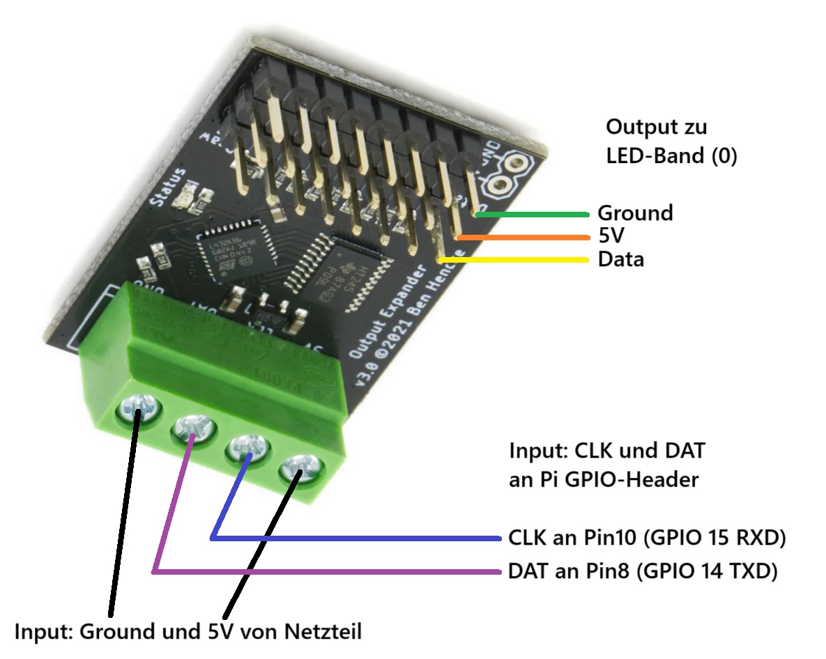
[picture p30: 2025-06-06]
hardware/images/LED-Steuerung Anschluesse.jpg

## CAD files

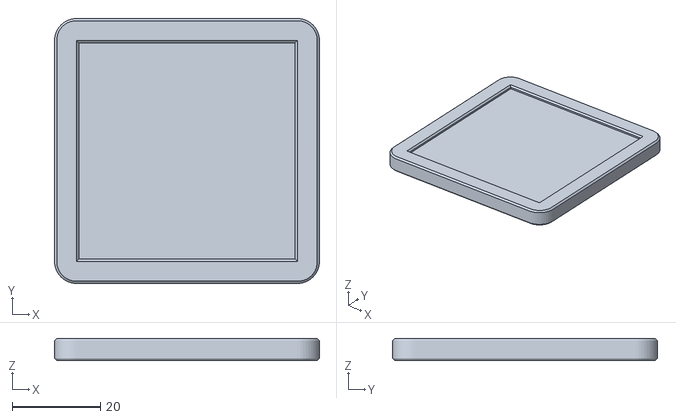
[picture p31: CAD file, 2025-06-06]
hardware/3D-Files/memory-cards-v4 60x60x5_R5.stl
60.0 x 60.0 x 5.00

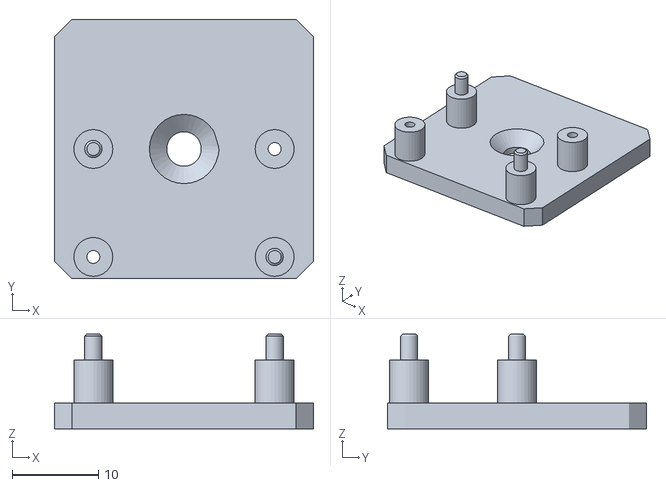
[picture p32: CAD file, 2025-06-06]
hardware/Prototype/Tisch/3D_Files/PI-CamHolder.stl
30.0 x 30.0 x 11.0

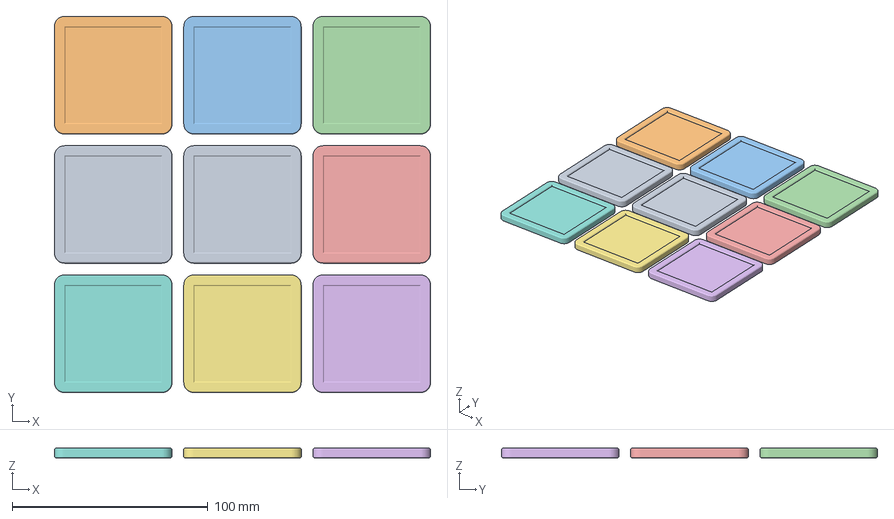
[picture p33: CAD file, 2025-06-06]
hardware/3D-Files/memory-cards-v5.3mf
192.0 x 192.0 x 5.00 mm

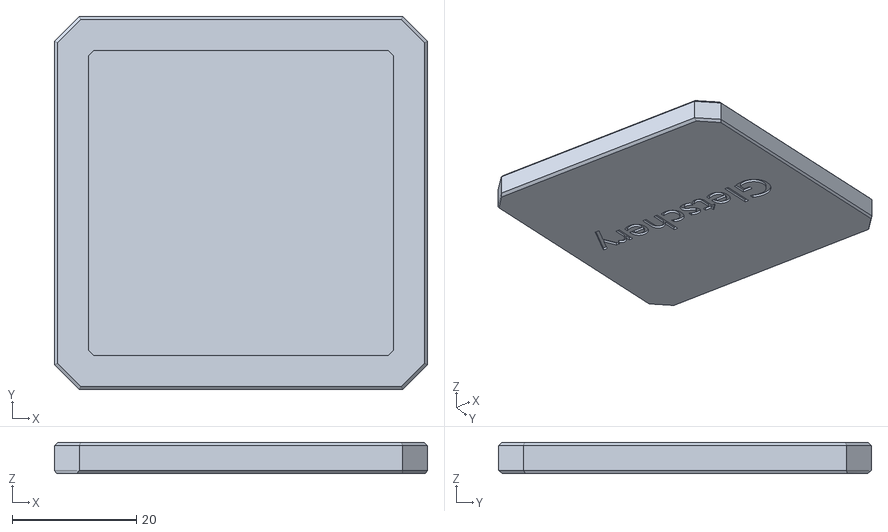
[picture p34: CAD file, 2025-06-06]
hardware/Prototype/MemoryCards/3D_Files/memory-cards-v1.stl
60.0 x 60.0 x 5.00

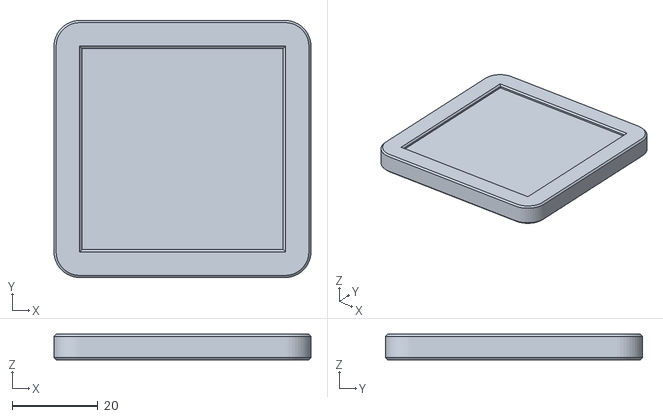
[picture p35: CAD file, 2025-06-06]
hardware/Prototype/MemoryCards/3D_Files/memory-cards-v4 60x60x6_R6.stl
60.0 x 60.0 x 6.00

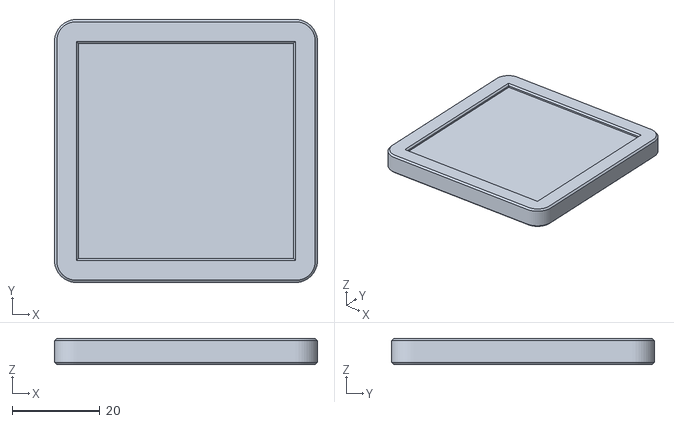
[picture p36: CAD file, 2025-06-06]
hardware/Prototype/MemoryCards/3D_Files/memory-cards-v4 60x60x6_R5.stl
60.0 x 60.0 x 6.00

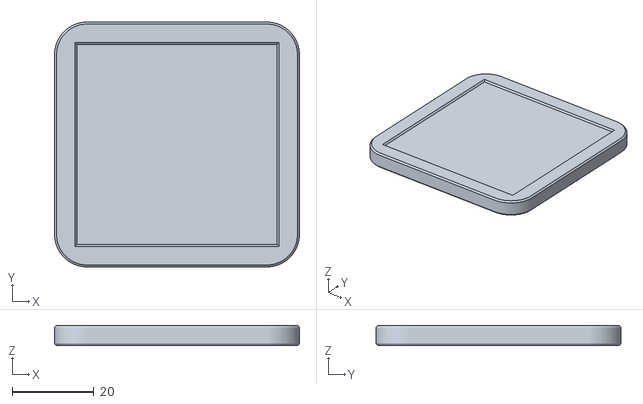
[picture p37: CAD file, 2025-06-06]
hardware/Prototype/MemoryCards/3D_Files/memory-cards-v2 60x60x5 radius.stl
60.0 x 60.0 x 5.00

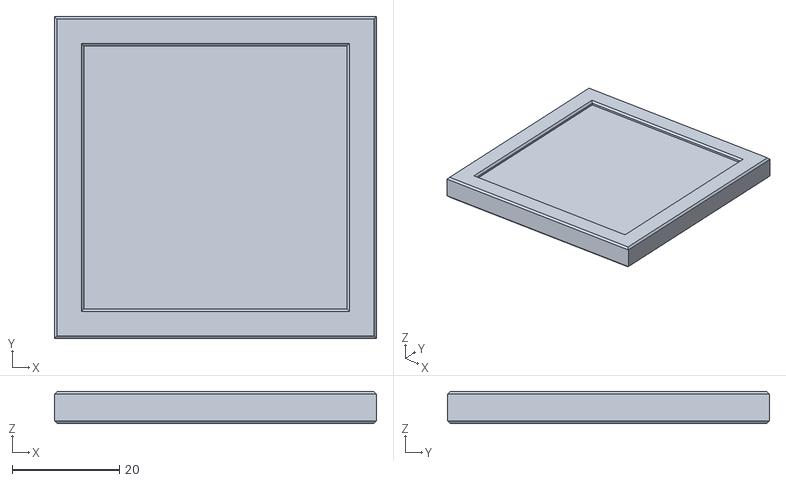
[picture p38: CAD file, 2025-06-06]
hardware/Prototype/MemoryCards/3D_Files/memory-cards-v3 60x60x6.stl
60.0 x 60.0 x 6.00

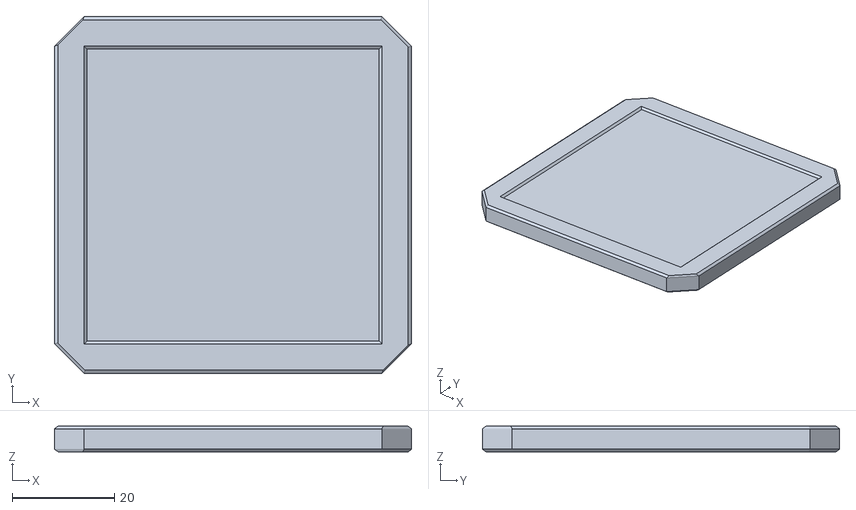
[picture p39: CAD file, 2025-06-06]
hardware/Prototype/MemoryCards/3D_Files/memory-cards-v2 70x70x5.stl
70.0 x 70.0 x 5.00

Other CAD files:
hardware/3D-Files/PI-CamHolderV2.stl
hardware/Prototype/MemoryCards/3D_Files/memory-cards-v4 60x60x5_R7.stl
hardware/Prototype/MemoryCards/3D_Files/memory-cards-v4 60x60x6_F5.stl
hardware/Prototype/MemoryCards/3D_Files/memory-cards-v4 60x60x5_R6.stl
hardware/Prototype/MemoryCards/3D_Files/memory-cards-v2 60x60x5.stl
hardware/Prototype/MemoryCards/3D_Files/memory-cards-v4 60x60x6_R7.stl
hardware/Prototype/MemoryCards/3D_Files/memory-cards-v4 60x60x5_F5.stl
hardware/Prototype/MemoryCards/3D_Files/memory-cards-v2 70x70x5 radius.stl
hardware/Prototype/MemoryCards/3D_Files/memory-cards-v3 60x60x7.stl

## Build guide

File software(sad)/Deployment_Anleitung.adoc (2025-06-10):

= Anleitung: Gletschery

== Depolyment

=== GitHub

* Repository-Link: https://github.com/fhnw-ip12-24vt/gletschery-docu/tree/main:[Link]

Laden Sie den Ordner files aus dem angegebenen GitHub-Repository herunter und speichern Sie die darin enthaltenen dateien auf dem Raspberry Pi an den beschriebenen Positionen.

=== Dateien

Die folgenden Datei- oder Dateigruppen sind an die jeweils angegebenen Verzeichnisse des primären Benutzers zu verschieben:

==== Gletscher-Bilder

Kopieren nach:

`~/Pictures/gletscherImages`

==== Icons und restliche Bilder

Kopieren nach:

`~/Pictures/generalImages`

==== JSON-Datei

Kopieren nach:

`~/Documents`

==== Bash-Skript: makeImage

Kopieren nach:

`~/Documents`

=== Autostart

Gletschery fungiert wie ein plug & play Spiel, das heisst,
wenn es am Strom angesteckt ist und eingeschaltet ist, bootet das Spiel automatisch.
Dies wird mithilfe eines Startskripts und Cron realisiert:

1. Erstelle folgendes Directory:
`/home/pi/scripts/`

2. Kopiere `startScript.sh` in `/home/pi/scripts/`

3. Gebe folgenden Befehl im Terminal ein: `crontab -e`
und wähle einen präferierten Text-Editor.

4. füge folgende Zeile hinzu: `@reboot sleep 10 && bash /home/pi/scripts/startScript.sh`

5. starte den cron service, indem folgende Befehle im Terminal eingegeben werden:

** `sudo systemctl daemon-reload`

** `sudo systemctl enable cron.service`

** `sudo systemctl start cron.service`

falls der Cron job scheduler bearbeitet werden muss, kann man dies mit dem folgenden command in bash tun:

`crontab -e`

Nun sollte Gletschery starten, wenn der Rasperry Pi eingeschaltet wird.

Wenn Gletschery geschlossen wird, wenn es am laufen ist (z.B. durch Alt+F4), muss man zuerst alle Instanzen von Gletschery beenden, bevor man es wieder starten kann.

Dies kann man entweder manuell machen mit Hilfe des folgendem bash commands:

`sudo pkill -f Gletschery`

oder man kann den command in einem executable bash script kopieren, und somit entweder bei Bedarf den Skript ausführen,
oder den script in eine benutzeridentifizierte Applikation auf den Rasperry Pi verwandeln.

Ein Tutorial wie das realisiert werden kann, findet man hier:

https://www.youtube.com/watch?v=Y9_3DlFqc1Q

[#_daten]
== Daten

Wenn daten angepasst werden sollen passiert dies Grundsätzlich über das JSON.Unten werden die Häufigsten fälle kurz beschrieben.

=== Gletscher hinzufügen oder entfernen
Um einen Gletscher hinzuzufügen muss im JSON unter dem Punkt pairs einen Neuen Eintrag hinzugefügt werden.Siehe JSON Template

=== Bilder ändern
Um Bilder aktueller gletscher zu ändern müssen diese nur Im ordner GletscherImages ausgetauscht werden.Achten sie darauf das das neue Bild den selben Namen wie das alte hat.Ansonsten muss dies im JSON angepasst werden.

=== Json übersicht
xref:JsonTemplate.adoc[Json Template]

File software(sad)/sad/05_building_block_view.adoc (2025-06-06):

[[section-building-block-view]]
== Bausteinsicht
[role="arc42help"]
****
.Inhalt
Die Bausteinsicht zeigt die statische Zerlegung des Systems in Bausteine (Module, Komponenten, Subsysteme, Klassen, Schnittstellen, Pakete, Bibliotheken, Frameworks, Schichten, Partitionen, Tiers, Funktionen, Makros, Operationen, Datenstrukturen, ...) sowie deren Abhängigkeiten (Beziehungen, Assoziationen, ...)

In der Analogie zum Hausbau bildet die Bausteinsicht den _Grundrissplan_.

.Motivation
Um sich einen Überblick über die Softwareseite des Produktes machen zu können werden verschiedene Diagramme erstellt. Diese sollen unter anderem die Struktur und den Ablauf des Codes einfach darstellen.

.Form
Die Bausteinsicht ist eine hierarchische Sammlung von Blackboxen und Whiteboxen (siehe Abbildung unten) und deren Beschreibungen.

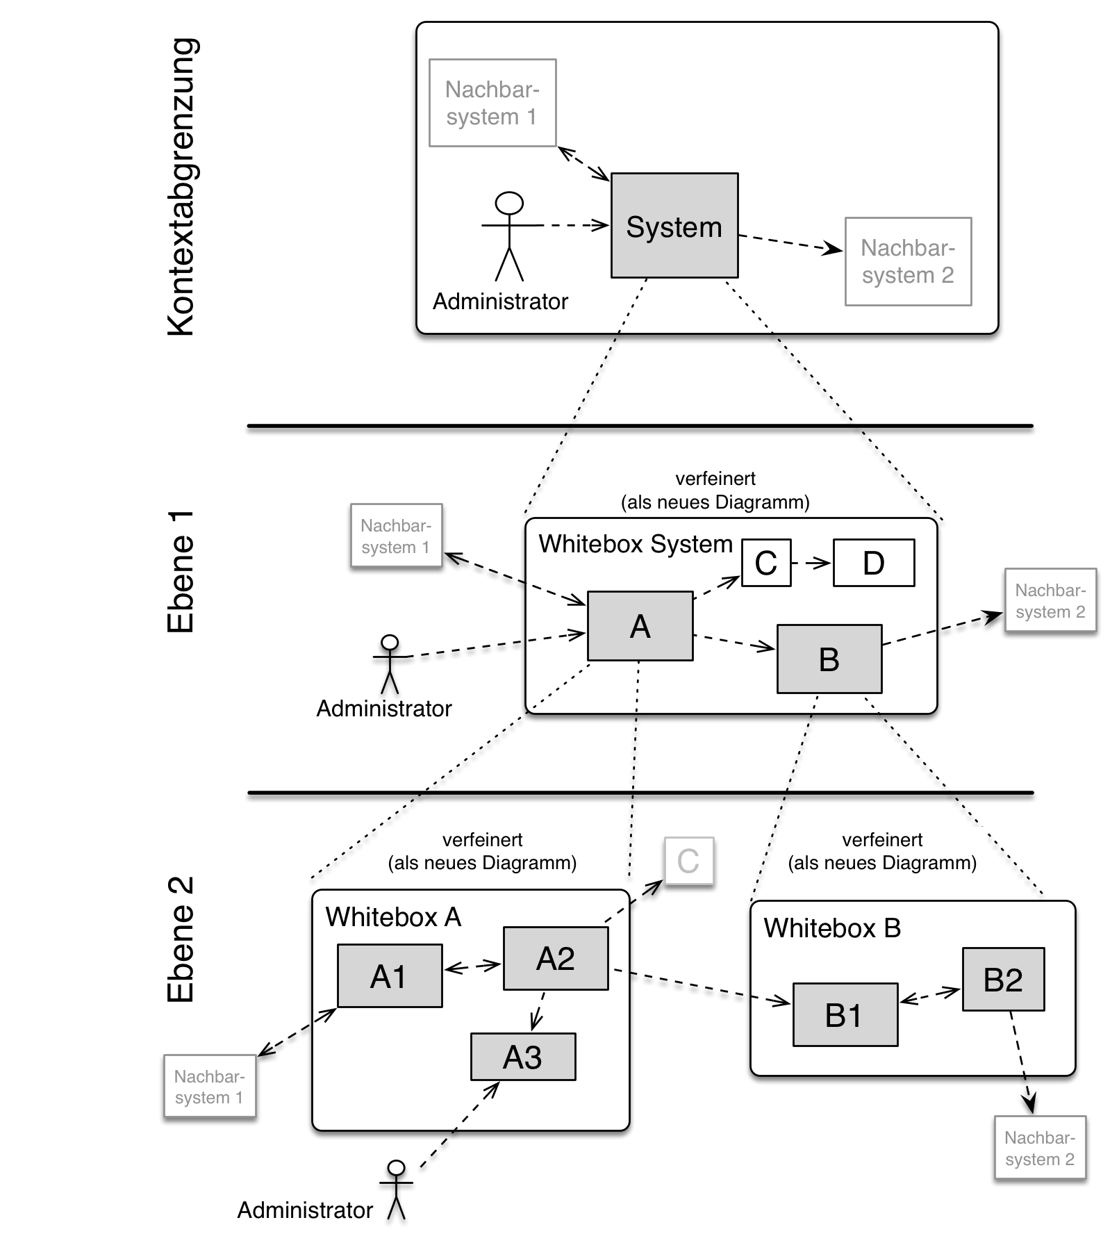
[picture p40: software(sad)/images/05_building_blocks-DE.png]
Hierarchie in der Bausteinsicht


*Ebene 1* ist die Whitebox-Beschreibung des Gesamtsystems, zusammen mit Blackbox-Beschreibungen der darin enthaltenen Bausteine.

*Ebene 2* zoomt in einige Bausteine der Ebene 1 hinein.
Sie enthält somit die Whitebox-Beschreibungen ausgewählter Bausteine der Ebene 1, jeweils zusammen mit Blackbox-Beschreibungen darin enthaltener Bausteine.

*Ebene 3* zoomt in einige Bausteine der Ebene 2 hinein, usw.

.Weiterführende Informationen

Siehe https://docs.arc42.org/section-5/[Bausteinsicht] in der online-Dokumentation (auf Englisch!).
****

=== Whitebox Gesamtsystem

[role="arc42help"]
****
An dieser Stelle beschreiben Sie die Zerlegung des Gesamtsystems anhand des nachfolgenden Whitebox-Templates.
Dieses enthält:

* Ein Übersichtsdiagramm
* die Begründung dieser Zerlegung
* Blackbox-Beschreibungen der hier enthaltenen Bausteine.
Dafür haben Sie verschiedene Optionen:

** in _einer_ Tabelle, gibt einen kurzen und pragmatischen Überblick über die enthaltenen Bausteine sowie deren Schnittstellen.
** als Liste von Blackbox-Beschreibungen der Bausteine, gemäß dem Blackbox-Template (siehe unten).
Diese Liste können Sie, je nach Werkzeug, etwa in Form von Unterkapiteln (Text), Unter-Seiten (Wiki) oder geschachtelten Elementen (Modellierungswerkzeug) darstellen.

* (optional:) wichtige Schnittstellen, die nicht bereits im Blackbox-Template eines der Bausteine erläutert werden, aber für das Verständnis der Whitebox von zentraler Bedeutung sind.
Aufgrund der vielfältigen Möglichkeiten oder Ausprägungen von Schnittstellen geben wir hierzu kein weiteres Template vor.
Im schlimmsten Fall müssen Sie Syntax, Semantik, Protokolle, Fehlerverhalten, Restriktionen, Versionen, Qualitätseigenschaften, notwendige Kompatibilitäten und vieles mehr spezifizieren oder beschreiben.
Im besten Fall kommen Sie mit Beispielen oder einfachen Signaturen zurecht.
****

=== Bausteinsicht Gletschery

.Begründung:
Die Bausteinsicht dient dazu eine technische Übersicht über das Produkt zu geben. Sie zeigt auf, wie das ganze System von Grund auf aufgebaut ist.

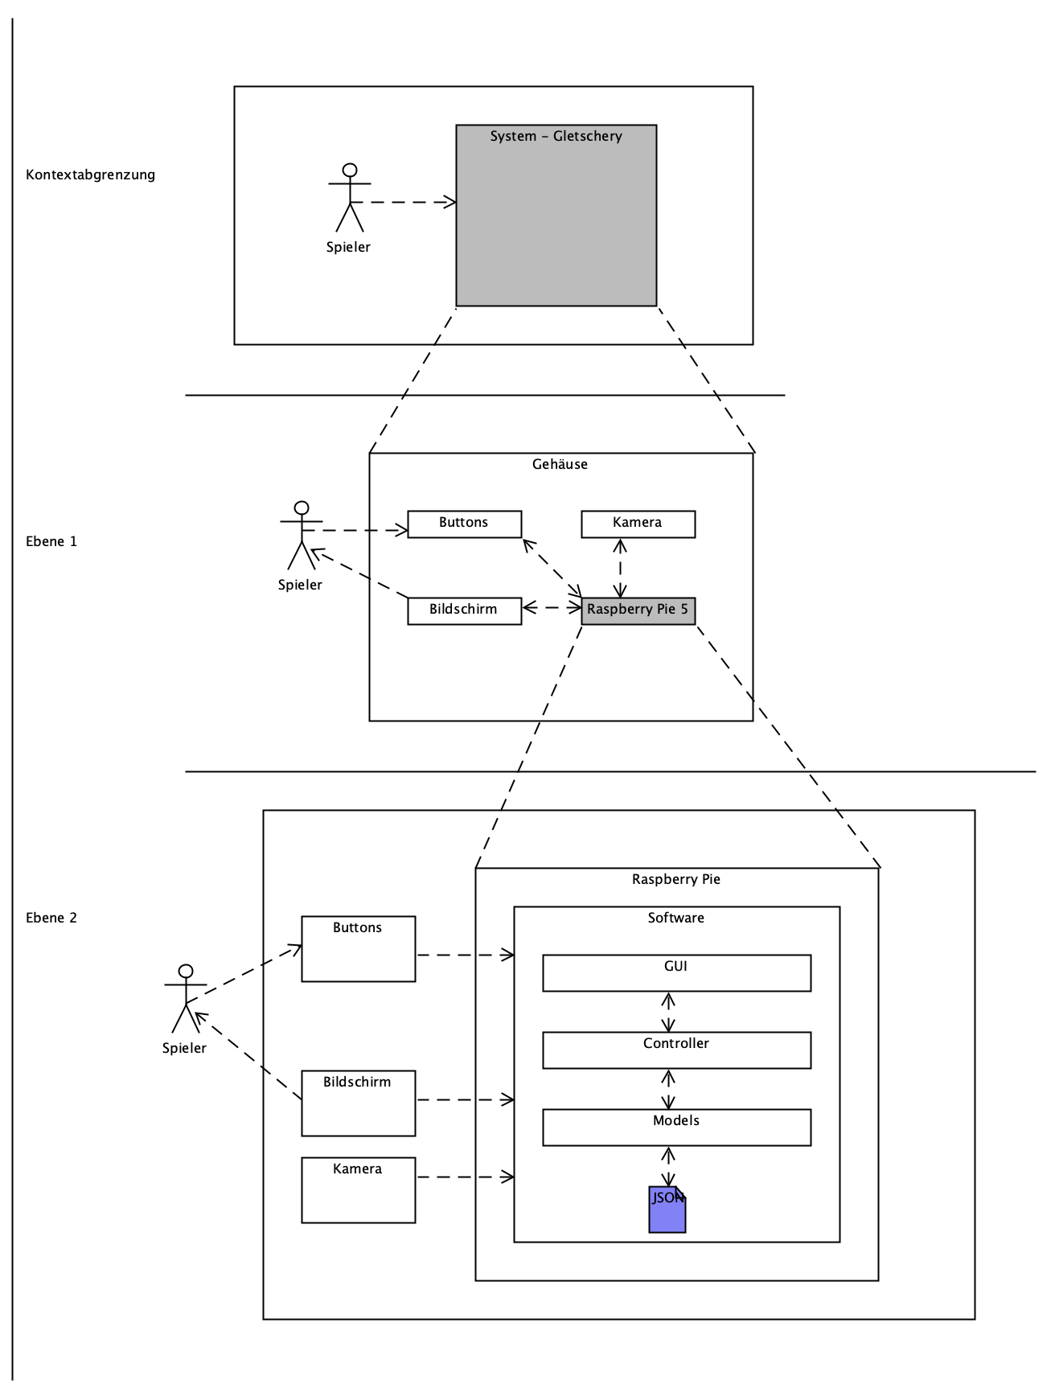
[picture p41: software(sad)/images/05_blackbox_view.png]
BlackboxView


Kontextabgrenzung::
Die Kontextabgrenzung stellt das ganze System und dessen Interaktion mit der Aussenwelt dar. In unserem Fall stellt sie die Interaktion mit unserem Akteur, dem Spieler, dar.

Ebene 1:: In der Ebene 1 wird dargestellt, aus welchen Teilkomponenten unser System besteht. Die Zentrale Komponente unseres Systems ist der Raspberry Pie, der die Software und damit die Spiellogik steuert. Den User-Input erhält er durch die Buttons, die im Gehäuse eingebaut sind. Die Kamera wird verwenden, um die Kartenpaare zu validieren. Der Bildschirm dient als Ausgabegerät für visuelle Ausgaben an den Spieler.

Ebene 2::
Gehäuse::: Das Gehäuse beinhaltet alle physischen Komponente des Produkts:
* Raspberry Pie
* Bildschirm
* Buttons
* Kamera

Die Software mit der ganzen Spiellogik interagiert mit dem Raspberry Pie und ist hauptsächlich in drei Packages aufgeteilt.

Wichtige Schnittstellen:: _<Beschreibung wichtiger Schnittstellen>_

[role="arc42help"]
****
Hier folgen jetzt Erläuterungen zu Blackboxen der Ebene 1.

Falls Sie die tabellarische Beschreibung wählen, so werden Blackboxen darin nur mit Name und Verantwortung nach folgendem Muster beschrieben:

[cols="1,2" options="header"]
|===
| **Name** | **Verantwortung**
| _<Blackbox 1>_ | _<Text>_
| _<Blackbox 2>_ | _<Text>_
|===

Falls Sie die ausführliche Liste von Blackbox-Beschreibungen wählen, beschreiben Sie jede wichtige Blackbox in einem eigenen Blackbox-Template.
Dessen Überschrift ist jeweils der Namen dieser Blackbox.
****

==== <Name Blackbox 1>

[role="arc42help"]
****
Beschreiben Sie die <Blackbox 1> anhand des folgenden Blackbox-Templates:

* Zweck/Verantwortung
* Schnittstelle(n), sofern diese nicht als eigenständige Beschreibungen herausgezogen sind.
Hierzu gehören eventuell auch Qualitäts- und Leistungsmerkmale dieser Schnittstelle.
* (Optional) Qualitäts-/Leistungsmerkmale der Blackbox, beispielsweise Verfügbarkeit, Laufzeitverhalten o. Ä.
* (Optional) Ablageort/Datei(en)
* (Optional) Erfüllte Anforderungen, falls Sie Traceability zu Anforderungen benötigen.
* (Optional) Offene Punkte/Probleme/Risiken
****

_<Zweck/Verantwortung>_

_<Schnittstelle(n)>_

_<(Optional) Qualitäts-/Leistungsmerkmale>_

_<(Optional) Ablageort/Datei(en)>_

_<(Optional) Erfüllte Anforderungen>_

_<(optional) Offene Punkte/Probleme/Risiken>_

==== <Name Blackbox 2>

_<Blackbox-Template>_

==== <Name Blackbox n>

_<Blackbox-Template>_

==== <Name Schnittstelle 1>

...

==== <Name Schnittstelle m>

=== Ebene 2

[role="arc42help"]
****
Beschreiben Sie den inneren Aufbau (einiger) Bausteine aus Ebene 1 als Whitebox.

Welche Bausteine Ihres Systems Sie hier beschreiben, müssen Sie selbst entscheiden.
Bitte stellen Sie dabei Relevanz vor Vollständigkeit.
Skizzieren Sie wichtige, überraschende, riskante, komplexe oder besonders volatile Bausteine.
Normale, einfache oder standardisierte Teile sollten Sie weglassen.
****

==== Whitebox _<Baustein 1>_

[role="arc42help"]
****
...zeigt das Innenleben von _Baustein 1_.
****

_<Whitebox-Template>_

==== Whitebox _<Baustein 2>_

_<Whitebox-Template>_

...

==== Whitebox _<Baustein m>_

_<Whitebox-Template>_

=== Ebene 3

[role="arc42help"]
****
Beschreiben Sie den inneren Aufbau (einiger) Bausteine aus Ebene 2 als Whitebox.

Bei tieferen Gliederungen der Architektur kopieren Sie diesen Teil von arc42 für die weiteren Ebenen.
****

==== Whitebox <_Baustein x.1_>

[role="arc42help"]
****
...zeigt das Innenleben von _Baustein x.1_.
****

_<Whitebox-Template>_

==== Whitebox <_Baustein x.2_>

_<Whitebox-Template>_

==== Whitebox <_Baustein y.1_>

_<Whitebox-Template>_

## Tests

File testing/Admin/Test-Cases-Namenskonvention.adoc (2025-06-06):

= Namenskonvention-TestCases

== Aufbau

**Ziffer 1:** Dokumentationsbereich

- 1: Hardware
- 2: Software
- 3: Testing

**Ziffer 2:** Rolle/Verantwortlichkeit

- 1: PM - Projektmanagement
- 2: RE - Requirements Engineering
- 3: UX - User Experience
- 4: SA - Software-Architektur
- 5: DEV/SC - Source Code
- 6: KOM - Kommunikation
- 7: TM - Software Testing

**Ziffer 4-5:** nummerisch aufsteigend oder Nummerierung Features

- 1: 01
- 2: 02
- 3: 03

**Ziffer 6-7:** Standardmässig 0, frei zur Versionierung oder Nummerierung der Use Cases

- 1: 00
- 1: 01

== Beispiel Ziffern Zuordnen

Test Case Funktionalität Bildschirm -> TC-32-0203

- 3: Test Case betrifft Dokumentationsbereich Testing
- 2: Test Case wird voraussichtlich von der Rolle RE ausgeführt
- 02: Test Case betrifft Feature 2 (Memorykarten (PUI))
- 03: TestCase handelt den Use Case 3 ab (Memorykarte aufdecken)

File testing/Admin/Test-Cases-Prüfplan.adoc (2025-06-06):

= Testplan

== Testziel

Dieser Testplan soll sicherstellen, dass die Software, Hardware sowie deren Integration reibungslos funktionieren. Zudem werden Aspekte der Benutzerfreundlichkeit überprüft. Die Tests dienen dazu, Fehler frühzeitig zu identifizieren und eine stabile sowie nutzerfreundliche Anwendung zu gewährleisten.

== Testumfang

Die Tests werden in vier Hauptkategorien unterteilt: Software, Hardware, Requirements und User Experience

=== 1. Software
|===
|Testtyp |Beschreibung |Methode

|Funktionstests |Überprüfung der einzelnen Softwarekomponenten |Automatisiert

|Systemtests |Testen der gesamten Software |Automatisiert

|Regressionstests |Testen bereits bestandener Tests zur kontinuierlichen Überprüfung |Automatisiert
|===

=== 2. Hardware
|===
|Testtyp |Beschreibung |Methode

|Funktionstests |Überprüfung der Grundfunktionen einzelner Hardwarekomponenten |Manuell (Kommandozeile)

|Regressionstests |Erneute Durchführung bestehender Tests nach Änderungen an der Hardware oder Software |Manuell (Kommandozeile)
|===

=== 3. Requirement
|===
|Testtyp |Beschreibung |Methode

|Funktionstests |Prüfung der Kommunikation zwischen Software und Hardware und Funktionalität Features |Manuell

|===

=== 4. User Experience
|===
|Testtyp |Beschreibung |Methode

|Verständlichkeitstest |Bewertung der Verständlichkeit der Systemanweisungen |Manuell

|Zugänglichkeitstest |Überprüfung der Zugänglichkeit des Systems für verschiedene Nutzer der Zielgruppe |Manuell

|Zufriedenheitstests |Messung der Nutzerzufriedenheit |Manuell
|===

== Teststrategie

Unterschiedliche Tests benötigen unterschiedliche Testmethoden, um eindeutige Ergebnisse zu erzielen.

=== 1. Software
Die Software wird von den Entwicklern mithilfe von JUnit-Tests und über eine Pipeline automatisiert getestet. Ein Merge in den main-Branch ist nur möglich, wenn alle Tests erfolgreich durchlaufen wurden.

=== 2. Hardware
Die Funktionalität der Hardware wird manuell via Kommandozeile überprüft. Dabei wird getestet, ob auf Befehl das erwartete Signal ausgegeben wird.

=== 3. Requirement
Das Zusammenspiel von Software und Hardware wird von Testern manuell überprüft. Hierfür werden alle Eingabemöglichkeiten getätigt und die Reaktion der Hardware beobachtet.

=== 4. User Experience
Die User Experience wird von der Zielgruppe bewertet. Hierfür wird den Endbenutzern ein Umfrageformular ausgehändigt, welches im Vorhinein erstellt wurde. Das Formular beinhaltet zwei Arten von Fragen:

==== 4.1 Geschlossene Fragen
Geschlossenen Fragen halten jeweils eine Likert-Skala mit vier Optionen (ja, eher ja, eher nein, nein) bereit. Die gerade Anzahl an Auswahlmöglichkeiten vermeiden eine neutrale Antwort und liefern ein eindeutigeres Ergebnis. Bei einer negativen Antwort wird ausserdem eine Begründung verlangt, für bessere Nachvollziehbarkeit.

==== 4.2 Offene Fragen
Offene Fragen sollen ausführlichere Meinungen motivieren und ein besseres Verständnis der Zielgruppe vermitteln.

== Testumgebung

* *Betriebssystem:* Windows/Rasperry Pi OS
* *Entwicklungsumgebung:* IntelliJ
* *Hardware:* Raspberry Pi, Raspberry Pi Kamera, Buttons(3x)
* *Testframeworks:* JUnit für Softwaretests

== Testrollen und Verantwortlichkeiten

|===
|Rolle |Verantwortlichkeiten

|Testmanager (TM) |Koordination der Teststrategie, Testdurchführung, Reporting

|Softwareentwickler (DEV) |Erstellung und Wartung automatisierter Tests

|Usability-Tester (UX) |Sammlung und Analyse von Nutzerfeedback
|===

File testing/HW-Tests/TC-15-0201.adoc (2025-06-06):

= Test Case Funktionalität Kamera 1

|===
|Doc-ID: | TC-15-0201
|Datum: | 28.11.2024
|Test durchgeführt durch: | Maurice Meier
|===

== Beschreibung

Der Test soll sicherstellen, dass das Kameramodul funktioniert und QR-Codes erkennen kann.

== Annahmen und Voraussetzungen
- Auf dem PI ist eine Software vorhanden, mit welcher ein QR-Code ausgelesen werden kann.

Alle Komponenten sind vorhanden:

- [x] Pi
- [x] Kameramodul
- [x] Datenkabel
- [x] Stromkabel

== Testdaten

- Beliebiger QR-Code dessen Inhalt bekannt ist.

== Auszuführende Schritte

. Vorhandenes Datenkabel am Kameramodul mit neu gekauftem ersetzen und mit Pi verbinden
. Pi an Strom anschliessen und einschalten
. Starten der benötigten Software zum Einlesen eines QR-Codes
. Beliebigen QR-Code mit bekanntem Inhalt im Sichtfeld der Kamera platzieren

== Erwartetes Ergebnis

Der QR-Code wird als solcher erkannt und dessen Inhalt im Terminal ausgegeben.

== Erzieltes Ergebnis

Test fehlgeschlagen!

Schlechte Lichtverhältnisse führen dazu, dass der QR-Code, besonders in den Ecken des Spielfeldes, nicht immer zuverlässig erkannt wird.

== Bemerkungen

Für die Fehlerbehebung und um die Kamera mit genügend Licht zu versorgen, werden im Inneren der Box LED-Streifen montiert. Beobachtung, ob das Problem dadurch gelöst werden kann.

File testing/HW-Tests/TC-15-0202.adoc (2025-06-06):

= Test Case Funktionalität Kamera 2

|===
|Doc-ID: | TC-15-0202
|Datum: | 29.11.2025
|Test durchgeführt durch: | Maurice Meier
|===

== Beschreibung

Der Test soll sicherstellen, dass das Kameramodul funktioniert und QR-Codes erkennen kann.

== Annahmen und Voraussetzungen

- Kameramodultest xref:TC-15-0201.adoc[TC-315-0201] wurde abgeschlossen.
- Auf dem PI ist eine Software vorhanden, mit welcher ein QR-Code ausgelesen werden kann.

Alle Komponenten sind vorhanden:

- [x] Pi
- [x] Kameramodul
- [x] Datenkabel
- [x] Stromkabel

== Testdaten

- Beliebiger QR-Code dessen Inhalt bekannt ist.
- Eingebaute LED-Streifen.

== Auszuführende Schritte

. LED-Streifen im Gehäuse montieren und mit Strom verbinden
. Pi an Strom anschliessen und einschalten
. Starten der benötigten Software zum Einlesen eines QR-Codes
. Beliebigen QR-Code mit bekanntem Inhalt im Sichtfeld der Kamera platzieren

=== Testablauf

. Starten der benötigten Software zum Einlesen eines QR-Codes
. Beliebigen QR-Code mit bekanntem Inhalt im Sichtfeld der Kamera platzieren
. Bei erfolgreichem Test, Wiederholung des Scanvorgangs an Rändern des Kamerasichtfeldes zur Überprüfung, ob der ganze Kamerabereich verwendet werden kann.

== Erwartetes Ergebnis

Der QR-Code wird als solcher erkannt und dessen Inhalt im Terminal ausgegeben.

== Erzieltes Ergebnis

Test fehlgeschlagen!

Schlechte Lichtverhältnisse führen dazu, dass der QR-Code, besonders in den Ecken des Spielfeldes, nicht immer zuverlässig erkannt wird.

== Bemerkungen

Durch die LED-Streifen werden die QR-Codes von Unten geblendet. Lösungen zur Fehlerbehebung werden ausgearbeitet.

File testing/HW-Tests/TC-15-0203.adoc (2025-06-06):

= Test Case Funktionalität Kamera 3

|===
|Doc-ID: | TC-15-0203
|Datum: | 11.12.2024
|Test durchgeführt durch: | Maurice Meier
|===

== Beschreibung

Der Test soll sicherstellen, dass das Kameramodul funktioniert und QR-Codes erkennen kann.

== Annahmen und Voraussetzungen

- Kameramodultest xref:TC-15-0202.adoc[TC-315-0202] wurde abgeschlossen.
- Auf dem PI ist eine Software vorhanden, mit welcher ein QR-Code ausgelesen werden kann.

Alle Komponenten sind vorhanden:

- [x] Pi
- [x] Kameramodul
- [x] Datenkabel
- [x] Stromkabel

== Testdaten

- Beliebiger QR-Code dessen Inhalt bekannt ist.
- Eingebaute LED-Streifen.

== Auszuführende Schritte

. LED-Streifen im Gehäuse montieren und mit Strom verbinden
. Pi an Strom anschliessen und einschalten
. Starten der benötigten Software zum Einlesen eines QR-Codes
. Beliebigen QR-Code mit bekanntem Inhalt im Sichtfeld der Kamera platzieren

=== Testablauf

. Starten der benötigten Software zum Einlesen eines QR-Codes
. Beliebigen QR-Code mit bekanntem Inhalt im Sichtfeld der Kamera platzieren
. Bei erfolgreichem Test, Wiederholung des Scanvorgangs an Rändern des Kamerasichtfeldes zur Überprüfung, ob der ganze Kamerabereich verwendet werden kann.

== Erwartetes Ergebnis

Der QR-Code wird als solcher erkannt und dessen Inhalt im Terminal ausgegeben.

== Erzieltes Ergebnis

Test fehlgeschlagen!

Die PI Kamera fokussiert teilweise falsch und erkennt die QR-Codes nicht zuverlässig.

== Bemerkungen

Lösungen zur Fehlerbehebung werden ausgearbeitet. Autofokus festlegen und Bilder in Schwarz-Weiss darstellen -> besserer Kontrast.

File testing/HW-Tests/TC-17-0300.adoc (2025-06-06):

= Test Case Funktionalität Gehäuse

|===
|Doc-ID: | TC-17-0300
|Datum: | 21.05.2025
|Test durchgeführt durch: | Nora Ramos
|===

== Beschreibung

Der Test soll sicherstellen, dass beim Einstecken des Stromkabels die grundlegende Systeminitialisierung funktioniert. Konkret wird geprüft, ob die LED leuchten, der Raspberry Pi hochfährt und die Buttons mit Strom versorgt werden.

== Annahmen und Voraussetzungen

- Stromzufuhr ist korrekt angeschlossen
- LED, Buttons und Raspberry Pi sind korrekt verdrahtet
- Software zur Systeminitialisierung ist auf dem Pi installiert
- Gehäuse ist vollständig montiert

== Testdaten

-

== Auszuführende Schritte

. Stromkabel an die Box anschliessen
. Beobachten, ob die LED-Streifen zu leuchten beginnen
. Prüfen, ob der Raspberry Pi hochfährt (über angeschlossenen Monitor)
. Beobachten, ob die Buttons Strom erhalten und leuchten

== Erwartetes Ergebnis

- Die LED beginnt zu leuchten
- Der Raspberry Pi startet korrekt
- Die Buttons erhalten Strom und zeigen dies durch Beleuchtung an

== Erzieltes Ergebnis

Hardwarekomponenten reagieren wie erwartet. System wird korrekt gestartet.

== Bemerkungen

Test erfolgreich abgeschlossen. Keine funktionalen Abweichungen festgestellt.

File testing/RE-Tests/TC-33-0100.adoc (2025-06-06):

= Test Case Spielspass

|===
|Doc-ID: |TC-33-0800
|Datum: | 28.03.2025 und 09.04.2025
|===

== Beschreibung

Der Test soll sicherstellen, dass

- Das Spiel soll Spass machen, motivierend sein und die Spieler emotional ansprechen

erfüllt werden kann.

== Bemerkung

Wird als Teil des Usability Testings in xref:../../UX-Tests/TC-33-0200.adoc[TC-33-0200] und xref:../../UX-Tests/TC-33-0201.adoc[TC-33-0201] abgehandelt.

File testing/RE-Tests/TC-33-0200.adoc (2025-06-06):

= Test Case Bewusstseinsvermittlung

|===
|Doc-ID: |TC-33-0900
|Datum: | 28.03.2025 und 09.04.2025
|===

== Beschreibung

Der Test soll sicherstellen, dass

- Das Spiel schafft Bewusstsein für die Auswirkungen der Gletscherschmelze durch interaktive Elemente und altersgerechte Information.

erfüllt werden kann.

== Bemerkung

Wird als Teil des Usability Testings in xref:../../UX-Tests/TC-33-0200.adoc[TC-33-0200] und xref:../../UX-Tests/TC-33-0201.adoc[TC-33-0201] abgehandelt.

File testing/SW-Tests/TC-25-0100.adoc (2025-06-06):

= Test Case Funktionalität Scanner

|===
|Doc-ID: | TC-25-0100
|Datum: | 28.11.2024
|Test durchgeführt durch: | Maurice Meier
|===

== Beschreibung

Der Test soll sicherstellen, dass die QR-Codes korrekt eingelesen werden.

== Annahmen und Voraussetzungen

- [x] Involvierte Hardwarekomponenten sind verbunden und in Betrieb (Pi, Kamera)
- [x] Das Gletschery-Projekt ist auf dem Raspberry Pi gestartet

== Testdaten

Beliebiger QR-Code dessen Inhalt bekannt ist.

== Auszuführende Schritte

. QR-Code über die Kamera halten
. Konsolenausgabe prüfen

== Erwartetes Ergebnis

Der Inhalt des QR-Codes wird korrekt ausgegeben.

== Erzieltes Ergebnis

Test bestanden!

Entspricht dem erwarteten Ergebnis.

== Bemerkungen

-

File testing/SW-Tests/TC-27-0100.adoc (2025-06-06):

= Test Case Projektabnahme

|===
|Doc-ID: | TC-27-0100
|Datum: | 04.06.2024
|Test durchgeführt durch: | Nora Ramos
|===

== Beschreibung

Der Test soll sicherstellen, dass sich die Software im finalen Zustand befindet und ein Spieldurchgang fehlerfrei durchlaufen werden kann.

== Annahmen und Voraussetzungen

- Das System ist vollständig implementiert und alle Funktionen sind integriert.

- Die Hardwarekomponenten sind korrekt installiert und betriebsbereit.

- Die Software läuft fehlerfrei und befindet sich im finalen Zustand.

== Testdaten

- Spieleranzahl: 2
- Spielmodus: Multiplayer
- 3D-gedruckte Memorykarten mit QR-Codes auf der Rückseite
- Stromversorgung und betriebsbereites Gerät

== Auszuführende Schritte

. Stromzufuhr herstellen.
. Beobachtung, ob das System automatisch hochgefahren wird.
. Startmenü erscheint auf dem Bildschirm.
. Spieler*in drückt auf START
. Spieler*in klickt durch die Spieleinführung und verteilt gemäss Spielanweisung Memorykarten auf dem Spielfeld.
. Spieler*in bestätigt und die erste Spielanweisung erscheint.
. Spieler*in dreht zwei Karten um und drückt auf den Scan-Knopf.
. Beobachtung, ob das Kartenpaar korrekt vom Scanner erkannt wird.
. Wiederholung der Schritte 6 - 8.
. Beobachtung, ob die Punkte korrekt gezählt und der richtige Sieger gekürt wird.
. Spieler*in navigiert zurück in das Startmenü.
. Ende des Spieldurchgangs.

== Erwartetes Ergebnis

. System startet zuverlässig und zeigt UI in Deutsch an.
. Kartenerkennung funktioniert innerhalb einer Sekunde pro Karte.
. Punkte werden korrekt gezählt und angezeigt.
. Spielablauf ist konsistent und verständlich.
. Spiel kann fehlerfrei und ohne Unterbrechung durchlaufen werden.

== Erzieltes Ergebnis

Sobald das Spiel mit Strom versorgt wird, startet das System auf und das Spiel kann gespielt werden.

== Bemerkungen

Test erfolgreich bestanden!

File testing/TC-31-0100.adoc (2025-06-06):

= Übergabeprotokoll Gletschery

|===
|Doc-ID: | TC-31-0100
|Datum: | tbd
|Übergabe durchgeführt durch: | Gletschery
|===

== Beschreibung

Dieses Dokument soll sicherstellen, dass alle benötigten Dokumente vollständig übergeben werden.

== Inhalt

=== Administratives

- [ ] Eine komplettes und unterschriebenes Übergabeprotokoll
- [ ] Zugriff auf das Code-Repository
- [ ] Zugriff auf das Docu-Repository

=== Hardware

- [ ] Die physische Box
- [ ] Stromkabel
- [ ] Memorykarten
- [ ] Ersatzkarten
- [ ] Ersatzhalterung PI-Kamera
- [ ] Dokumentation mit Teilliste und Abmessungen

=== Software

- [ ] Dokumentation in Form des SAD
- [ ] Deployment-Anleitung

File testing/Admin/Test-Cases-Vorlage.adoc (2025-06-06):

= Test Case (_TestNameHierEintragen_)

|===
|Doc-ID: |TC-000-000
|Datum: | dd.mm.yyyy
|Test durchgeführt durch: | (Namen hier eintragen)
|===

== Beschreibung

(_Bitte eine Beschreibung des Tests hier eintragen oder ergänzen_)

== Annahmen und Voraussetzungen

(_Bitte Annahmen und Voraussetzungen hier eintragen oder ergänzen_)

== Testdaten

(_Bitte Testdaten hier eintragen wenn vorhanden; ansonsten -_)

== Auszuführende Schritte

(_Bitte ausgeführte Schritte hier eintragen oder ergänzen_)

. Schritt Eins
. Schritt Zwei

== Erwartetes Ergebnis

(Test bestanden! / nicht bestanden)

(_Bitte erwartetes Ergebnis hier eintragen oder ergänzen_)

== Erzieltes Ergebnis

(_Bitte erzieltes Ergebnis hier eintragen_)

== Bemerkungen

(_Bitte hier Bemerkungen, Abweichungen, Ergänzungen oder Massnahmen zu diesem TestCase eintragen; ansonsten -_)

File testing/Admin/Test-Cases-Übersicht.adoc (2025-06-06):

= Übersicht Test Cases

== Übernahmeprotokoll
|===
|Test Case |Name

|xref:../TC-31-0100.adoc[TC-31-0100] |Übernahmeprotokoll Gletschery
|xref:../TC-31-0200.adoc[TC-31-0200] | Übernahmeprotokoll Primeo Energie

|===

== Hardware Tests
|===
|Test Case |Name

|xref:../HW-Tests/TC-17-0100.adoc[TC-17-0100] |Übersicht Funktionalität Bildschirm
|xref:../HW-Tests/TC-15-0200.adoc[TC-15-0200]
| Übersicht Funktionalität Kamera
|xref:../HW-Tests/TC-17-0300.adoc[TC-17-0300]
 |Systeminitialisierung
|===

== RE-Tests
=== Funktionale Anforderungen
|===
|Test Case |Name

|xref:../RE-Tests/Funktionale Anforderungen/TC-32-0101.adoc[TC-32-0101]
|Feature 1 -  UC01
|xref:../RE-Tests/Funktionale Anforderungen/TC-32-0102.adoc[TC-32-0102]
|Feature 1 - UC02
|xref:../RE-Tests/Funktionale Anforderungen/TC-32-0203.adoc[TC-32-0203]
|Feature 2 - UC03
|xref:../RE-Tests/Funktionale Anforderungen/TC-32-0204.adoc[TC-32-0204]
|Feature 2 - UC04
|xref:../RE-Tests/Funktionale Anforderungen/TC-32-0305.adoc[TC-32-0305]
|Feature 3 - UC05
|xref:../RE-Tests/Funktionale Anforderungen/TC-32-0306.adoc[TC-32-0306]
|Feature 3 - UC06
|xref:../RE-Tests/Funktionale Anforderungen/TC-32-0307.adoc[TC-32-0407]
|Feature 4 - UC07
|xref:../RE-Tests/Funktionale Anforderungen/TC-32-0508.adoc[TC-32-0508]
|Feature 5 - UC08
|xref:../RE-Tests/Funktionale Anforderungen/TC-32-0509.adoc[TC-32-0509]
|Feature 5 - UC09
|xref:../RE-Tests/Funktionale Anforderungen/TC-32-0610.adoc[TC-32-0610]
|Feature 6 - UC10
|xref:../RE-Tests/Funktionale Anforderungen/TC-32-0611.adoc[TC-32-0611]
|Feature 6 - UC11
|xref:../RE-Tests/Funktionale Anforderungen/TC-32-0712.adoc[TC-32-0712]
|Feature 7 - UC12
|xref:../RE-Tests/Funktionale Anforderungen/TC-32-0713.adoc[TC-32-0713]
|Feature 7 - UC13
|xref:../RE-Tests/Funktionale Anforderungen/TC-32-0814.adoc[TC-32-0814]
|Feature 8 -UC14
|xref:../RE-Tests/Funktionale Anforderungen/TC-32-0815.adoc[TC-32-0815]
|Feature 8 - UC15
|xref:../RE-Tests/Funktionale Anforderungen/TC-32-0816.adoc[TC-32-0816]
|Feature 8 - UC16
|xref:../RE-Tests/Funktionale Anforderungen/TC-32-0917.adoc[TC-32-0917]
|Feature 9 - UC17
|xref:../RE-Tests/Funktionale Anforderungen/TC-32-0918.adoc[TC-32-0918]
|Feature 9 - UC18

|===

=== Qualitätsanforderungen
|===
|Test Case |Name

|xref:../RE-Tests/Qualitätsanforderungen/TC-32-0100.adoc[TC-32-0100]
|Q01 - Leistungseffizienz
|xref:../RE-Tests/Qualitätsanforderungen/TC-32-0200.adoc[TC-32-0200]
|Q02 - Benutzerfreundlichkeit
|xref:../RE-Tests/Qualitätsanforderungen/TC-32-0300.adoc[TC-32-0300]
|Q03 - Benutzerfreundlichkeit
|xref:../RE-Tests/Qualitätsanforderungen/TC-32-0400.adoc[TC-32-0400]
|Q04 - Benutzerfreundlichkeit
|xref:../RE-Tests/Qualitätsanforderungen/TC-32-0500.adoc[TC-32-0500]
|Q05 - Benutzerfreundlichkeit
|xref:../RE-Tests/Qualitätsanforderungen/TC-32-0600.adoc[TC-32-0600]
| Q06 - Benutzerfreundlichkeit
|xref:../RE-Tests/Qualitätsanforderungen/TC-32-0700.adoc[TC-32-0700]
| Q07 - Benutzerfreundlichkeit
|xref:../RE-Tests/Qualitätsanforderungen/TC-32-0800.adoc[TC-32-0800]
| Q08 - Wartbarkeit
|===

Nicht direkt in den Requirements definiert, dennoch interessante und wichtige Indikatoren für die Entwicklung des Gletschery:
|===
|Test Case | Name

|xref:../RE-Tests/TC-33-0100.adoc[TC-33-0100] | Spielspass
|xref:../RE-Tests/TC-33-0200.adoc[TC-33-0200] | Bewusstseinsvermittlung
|===

== Software Tests
|===
|Test Case |Name

|xref:../SW-Tests/TC-25-0100.adoc[TC-25-0100]
|Funktionalität Scanner
|xref:../SW-Tests/TC-27-0100.adoc[TC-27-0100]
|Projektabnahme
|===

== Usability Tests
|===
|Test Case |Name

|xref:../UX-Tests/TC-33-0100.adoc[TC-33-0100] |Q02 & Q03 - Benutzerfreundlichkeit
|xref:../UX-Tests/TC-33-0101.adoc[TC-33-0101] |Q02 & Q03 - Benutzerfreundlichkeit
|xref:../UX-Tests/TC-33-0200.adoc[TC-33-0200] |Spielspass & Bewusstseinsvermittlung
|xref:../UX-Tests/TC-33-0201.adoc[TC-33-0201] |Spielspass & Bewusstseinsvermittlung

|===

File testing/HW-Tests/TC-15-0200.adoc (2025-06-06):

= Übersicht Funktionalität Kamera

|===
|Doc-ID: | TC-15-0200
|Test durchgeführt durch: | Maurice Meier
|===

== Beschreibung

Diese Übersicht fasst alle Test Cases zusammen, welche sicherstellen, dass das Kameramodul funktioniert und QR-Codes erkennen kann.

== Annahmen und Voraussetzungen

Alle Komponenten sind vorhanden:

- [x] Pi
- [x] Kameramodul
- [x] Datenkabel
- [x] Stromkabel

- Auf dem PI ist eine Software vorhanden, mit welcher ein QR-Code ausgelesen werden kann.

== Testdaten

- Kartenraster für ideale Ausrichtung auf der Plexiglasplatte.
- Beliebiger QR-Code dessen Inhalt bekannt ist.

== Auszuführende Schritte

- [x] Geeigneten Rahmen auswählen (Karton, Holz, Plastik)
- [x] Kameramodul und Pi platzieren und befestigen
- [x] Elektronische Komponenten verbinden
- [x]  Rahmen auf Spielfläche (Plexiglas) fixieren
- [x] Monitor anschliessen

=== Testablauf

. Starten der benötigten Software zum Einlesen eines QR-Codes
. Beliebigen QR-Code mit bekanntem Inhalt im Sichtfeld der Kamera platzieren
. Bei erfolgreichem Test, Wiederholung des Scanvorgangs an Rändern des Kamerasichtfeldes zur Überprüfung, ob der ganze Kamerabereich verwendet werden kann.

== Erwartetes Ergebnis

Der QR-Code wird als solcher erkannt und dessen Inhalt im Terminal ausgegeben.

== Erzieltes Ergebnis

|===
| Datum | Ergebnis | Bemerkung

| 28.11.2024 | Fehlgeschlagen | xref:../HW-Tests/TC-15-0201.adoc[TC-15-0201:] Probleme Erkennung in den Ecken des Spielfeldes
| 29.11.2024 | Fehlgeschlagen | xref:../HW-Tests/TC-15-0202.adoc[TC-15-0202:] Probleme Erkennung in den Ecken des Spielfeldes
| 11.12.2024 | Fehlgeschlagen | xref:../HW-Tests/TC-15-0203.adoc[TC-15-0203:] Probleme Autofokus
| 19.01.2025 | Fehlgeschlagen | xref:../HW-Tests/TC-15-0204.adoc[TC-15-0204:] Probleme mit der Ausrichtung der QR-Codes
| 30.04.2025 | Bestanden | -
| 06.05.2025 | Bestanden | -
| 21.05.2025 | Bestanden | -

|===

== Bemerkungen

Die Funktionalität der Kamera wurde im Verlauf des Projektes wiederholt getestet. Anfängliche Probleme konnten behoben werden und es wurden keine weiteren funktionalen Abweichungen festgestellt.

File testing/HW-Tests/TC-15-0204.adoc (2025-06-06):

= Test Case Funktionalität Kamera 4

|===
|Doc-ID: | TC-15-0204
|Datum: | 19.01.2025
|Test durchgeführt durch: | Maurice Meier
|===

== Beschreibung

Der Test soll sicherstellen, dass das Kameramodul funktioniert und QR-Codes erkennen kann.

== Annahmen und Voraussetzungen

- Kameramodultest xref:TC-15-0203.adoc[TC-315-0203] wurde abgeschlossen.
- Auf dem PI ist eine Software vorhanden, mit welcher ein QR-Code ausgelesen werden kann.

Alle Komponenten sind vorhanden:

- [x] Pi
- [x] Kameramodul
- [x] Datenkabel
- [x] Stromkabel

== Testdaten

- Beliebiger QR-Code dessen Inhalt bekannt ist.
- Eingebaute und abgeschirmte LED-Streifen (Vertiefung im Gehäuse)
- Bilder für den Scan sind in Schwarz-Weiss hinterlegt.
- Autofokus

== Auszuführende Schritte

. LED-Streifen im Gehäuse montieren und mit Strom verbinden
. Pi an Strom anschliessen und einschalten
. Starten der benötigten Software zum Einlesen eines QR-Codes
. Beliebigen QR-Code mit bekanntem Inhalt im Sichtfeld der Kamera platzieren

=== Testablauf

. Starten der benötigten Software zum Einlesen eines QR-Codes
. Beliebigen QR-Code mit bekanntem Inhalt im Sichtfeld der Kamera platzieren
. Bei erfolgreichem Test, Wiederholung des Scanvorgangs an Rändern des Kamerasichtfeldes zur Überprüfung, ob der ganze Kamerabereich verwendet werden kann.

== Erwartetes Ergebnis

Der QR-Code wird als solcher erkannt und dessen Inhalt im Terminal ausgegeben.

== Erzieltes Ergebnis

Test fehlgeschlagen!

Die Kamera kann QR-Codes nicht zuverlässig erkennen, wenn sie in verschiedenen Winkeln auf der Spieloberfläche liegen.

== Bemerkungen

Lösungen zur Fehlerbehebung werden ausgearbeitet. Ein Raster aus Holz mit Einlassungen, in welche die Karten hineingelegt werden können, sorgt dafür, dass die Karten alle gleich ausgerichtet sind.

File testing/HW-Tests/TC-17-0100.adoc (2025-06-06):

= Übersicht Funktionalität Bildschirm

|===
|Doc-ID: | TC-17-0100
|Test durchgeführt durch: | Dominik Scheuber
|===

== Beschreibung

Diese Übersicht fasst alle Test Cases zusammen, welche sicherstellen, dass der externe Bildschirm vom System erkannt wird und eine Ausgabe produziert.

== Annahmen und Voraussetzungen

Alle Komponenten sind vorhanden:

- [x] Pi
- [x] Bildschirm
- [x] Datenkabel (HDMI)
- [x] Stromkabel

== Testdaten

-

== Auszuführende Schritte

. Pi und Bildschirm an Strom anschliessen
. Pi und Bildschirm mit HDMI Kabel verbinden

== Erwartetes Ergebnis

Pi erkennt Bildschirm und startet automatisch die Ausgabe der Raspberry-PI Desktop-Umgebung, welche auf dem Bildschirm sichtbar ist.

== Erzieltes Ergebnis

|===
| Datum | Ergebnis | Bemerkung

| 28.11.2024 | Bestanden | -
| 29.11.2024 | Bestanden | -
| 11.12.2024 | Bestanden | -
| 19.01.2025 | Bestanden | -
| 30.04.2025 | Bestanden | -
| 06.05.2025 | Bestanden | -
| 21.05.2025 | Bestanden | -

|===

== Bemerkungen

Die Funktionalität des Bildschirms wurde im Verlauf des Projektes wiederholt getestet. Es wurden keine funktionalen Abweichungen festgestellt.

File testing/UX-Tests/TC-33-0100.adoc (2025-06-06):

= Test Case Q02 & Q03

|===
|Doc-ID: |TC-33-0100
|Datum: |28.03.2025
|Test durchgeführt durch: | Nora, Patrick, Aswin
|===

== Beschreibung

Der Test soll sicherstellen, dass

- **Q02: **Das Spiel benötigt keine separate Anleitung und erklärt sich durch das Design und die Interaktion von selbst.
- **Q03: **Der Inhalt ist für die Zielgruppe angemessen und verständlich formuliert.

erfüllt werden kann.

== Annahmen und Voraussetzungen

- Fragebogen ist erstellt und an Spieler*innen verteilt
- QR-Code Erkennung und Bildschirmausgabe sind implementiert
- Hardwarekomponente (Knopf) für Einreichung Spielzug ist eingebaut

== Testdaten

- 6 Testpersonen (Alter: 12 bis 16 Jahre)

- xref:Fragebogen UX-Testing 2.0.pdf[Fragebogen UX-Testing 2.0]

== Auszuführende Schritte

. Einführung in Usability Test durch UX und Aufbau Prototyp/Testumgebung
. Übergabe Fragebogen an Testpersonen
. Spieler*innen lesen in Ruhe den Fragebogen durch
. Erklärung Projektstand und Ablauf Testing
. **Spieler*innen spielen das Spiel**
. **Spieler*innen füllen in Ruhe den Fragebogen aus**
. Fragen klären & nochmals mündlich Feedback einholen
. Abbau Prototyp/Testumgebung

== Erwartetes Ergebnis

Der Fragebogen ist von jeder Testperson vollständig ausgefüllt.

Die Bewertung von Frage Nr. 02, 03 und 04 fällt in 5 von 6 Fällen positiv aus.

== Protokoll Durchführung

. Einführung Teammitglieder und Vorstellung Projekt
. Erklärung Spielablauf und Funktionalität mit Betätigung Button und Scanvorgang
. Abgabe Fragebogen und Zeit für die Spieler die Fragen durchzulesen
. Vorschau der fertigen Screens im Figma und wie sich die Spieler die Darstellung während dem Spiel vorstellen können
. Platzierung der Karten auf dem Spielfeld
. **Spielen** -> Spieler melden, wann der Button von uns gedrückt werden soll
. Fragen klären und Zeit um Fragebogen auszufüllen

=== Feedback
- Idee: Schwarzes oder weisses Raster (Folie?) um die Platzierung der Karten zu handhaben
- Wie weiss das System, dass das Spiel fertig ist? Anhand der vordefinierten Library -> Verbesserung: Ergänzen, dass Anzahl der Kartenpaare selber gewählt werden kann

== Erzieltes Ergebnis

Test bestanden!

Entspricht dem erwarteten Ergebnis.

== Bemerkungen

- Frage Nr. 02: 5 positive Antworten (JA oder ähnlich), 1 mittelmässige Antwort
- Frage Nr. 03: 6 positiv (gut oder sehr gut)
- Frage Nr. 04: 6 positiv (gut oder sehr gut)

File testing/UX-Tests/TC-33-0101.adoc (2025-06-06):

= Test Case Q02 & Q03

|===
|Doc-ID: |TC-33-0101
|Datum: | 09.04.2025
|Test durchgeführt durch: | Nora, Patrick, Aswin, Dominik
|===

== Beschreibung

Der Test soll sicherstellen, dass

- **Q02: **Das Spiel benötigt keine separate Anleitung und erklärt sich durch das Design und die Interaktion von selbst.
- **Q03: **Der Inhalt ist für die Zielgruppe angemessen und verständlich formuliert.

erfüllt werden kann.

== Annahmen und Voraussetzungen

- QR-Code Erkennung und Bildschirmausgabe sind implementiert
- Hardwarekomponente (Knopf) für Einreichung Spielzug ist eingebaut
- Memorykarten sind mit Bildern versehen

== Testdaten

- Testpersonen (Alter: 9 bis 12 Jahre)

== Auszuführende Schritte

. Einführung in Usability Test durch UX und Aufbau Prototyp/Testumgebung
. Erklärung Projektstand und Ablauf Testing
. **Spieler*innen spielen das Spiel**
. **Beobachtung und Feedback einholen durch Team**
. Fragen klären & nochmals mündlich Feedback einholen
. Abbau Prototyp/Testumgebung

== Erwartetes Ergebnis

Das Spiel ist klar verständlich und die Testpersonen können einen reibungslosen Durchgang spielen.

== Erzieltes Ergebnis

Test teilweise bestanden!

== Bemerkungen

Für die Kinder ist leicht verständlich was sie machen müssen und es entsteht schnell ein angenehmer Spielfluss.

Jedoch haben wir für das Testing die Bilder und QR-Codes von 00 bis 08 und die Nummer 10 verwendet. Dadurch, dass es einen Unterbruch in den Nummern gab, funktionierte das Scannen für die Nummer 10 nicht und der Spielfluss war unterbrochen.

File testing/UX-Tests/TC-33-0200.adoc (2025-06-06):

= Test Case Spielspass & Bewusstseinsvermittlung

|===
|Doc-ID: |TC-533-020
|Datum: | 28.03.2025
|Test durchgeführt durch: | Nora, Patrick, Aswin
|===

== Beschreibung

Der Test soll sicherstellen, dass

- Das Spiel soll Spass machen, motivierend sein und die Spieler emotional ansprechen
- Das Spiel schafft Bewusstsein für die Auswirkungen der Gletscherschmelze durch interaktive Elemente und altersgerechte Information.

erfüllt werden kann.

== Annahmen und Voraussetzungen

- Fragebogen ist erstellt und an Spieler*innen verteilt
- QR-Code Erkennung und Bildschirmausgabe sind implementiert
- Hardwarekomponente (Knopf) für Einreichung Spielzug ist eingebaut

== Testdaten

- 6 Testpersonen (Alter: 12 bis 16 Jahre)

- xref:Fragebogen UX-Testing 2.0.pdf[Fragebogen UX-Testing 2.0]

== Auszuführende Schritte

. Einführung in Usability Test durch UX und Aufbau Prototyp/Testumgebung
. Übergabe Fragebogen an Testpersonen
. Spieler*innen lesen in Ruhe den Fragebogen durch
. Erklärung Projektstand und Ablauf Testing
. **Spieler*innen spielen das Spiel**
. **Spieler*innen füllen in Ruhe den Fragebogen aus**
. Fragen klären & nochmals mündlich Feedback einholen
. Abbau Prototyp/Testumgebung

== Erwartetes Ergebnis

Der Fragebogen ist von jeder Testperson vollständig ausgefüllt.

Die Bewertung von Frage Nr. 11, 12 und 13 fällt in 5 von 6 Fällen positiv aus.

== Protokoll Durchführung

. Einführung Teammitglieder und Vorstellung Projekt
. Erklärung Spielablauf und Funktionalität mit Betätigung Button und Scanvorgang
. Abgabe Fragebogen und Zeit für die Spieler die Fragen durchzulesen
. Vorschau der fertigen Screens im Figma und wie sich die Spieler die Darstellung während dem Spiel vorstellen können
. Platzierung der Karten auf dem Spielfeld
. **Spielen** -> Spieler melden, wann der Button von uns gedrückt werden soll
. Fragen klären und Zeit um Fragebogen auszufüllen

=== Feedback
- Idee: Schwarzes oder weisses Raster (Folie?) um die Platzierung der Karten zu handhaben
- Wie weiss das System, dass das Spiel fertig ist? Anhand der vordefinierten Library -> Verbesserung: Ergänzen, dass Anzahl der Kartenpaare selber gewählt werden kann

== Erzieltes Ergebnis

Test bestanden!

Entspricht dem erwarteten Ergebnis.

== Bemerkungen

- Frage Nr. 11: 5 positiv (gut oder sehr gut), 1 negativ (schlecht oder sehr schlecht)
- Frage Nr. 12: 6 Antworten mit JA
- Frage Nr. 13: 6 positiv (gut oder sehr gut)

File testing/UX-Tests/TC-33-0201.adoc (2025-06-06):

= Test Case Spielspass & Bewusstseinsvermittlung

|===
|Doc-ID: |TC-33-0201
|Datum: | 09.04.2025
|Test durchgeführt durch: | Nora, Patrick, Aswin, Dominik
|===

== Beschreibung

Der Test soll sicherstellen, dass

- Das Spiel soll Spass machen, motivierend sein und die Spieler emotional ansprechen
- Das Spiel schafft Bewusstsein für die Auswirkungen der Gletscherschmelze durch interaktive Elemente und altersgerechte Information.

erfüllt werden kann.

== Annahmen und Voraussetzungen

- QR-Code Erkennung und Bildschirmausgabe sind implementiert
- Hardwarekomponente (Knopf) für Einreichung Spielzug ist eingebaut
- Memorykarten sind mit Bildern versehen

== Testdaten

- Testpersonen (Alter: 9 bis 12 Jahre)

== Auszuführende Schritte

. Einführung in Usability Test durch UX und Aufbau Prototyp/Testumgebung
. Erklärung Projektstand und Ablauf Testing
. **Spieler*innen spielen das Spiel**
. **Beobachtung und Feedback einholen durch Team**
. Fragen klären & nochmals mündlich Feedback einholen
. Abbau Prototyp/Testumgebung

== Erwartetes Ergebnis

Das Spiel macht Testpersonen Freude und sie lernen mehr über die Schweizer Gletscher.

== Erzieltes Ergebnis

Test bestanden!

== Bemerkungen

Es macht den Kindern Spass das Spiel zu spielen und jedes von ihnen hat etwas Neues über einen Gletscher oder sogar einen neuen Gletscher (kennen-)gelernt.

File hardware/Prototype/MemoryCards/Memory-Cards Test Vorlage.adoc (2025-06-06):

= Test (nummer)

*Datum:*

*Testziel:*

- [ ]

'''

*Testdetails:*

Konstruktion Details

- ()

3D-Druck Details

- ()

'''

*Ergebnis:*

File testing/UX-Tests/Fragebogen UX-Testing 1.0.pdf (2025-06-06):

# Fragebogen Gletschery

- Wie hast du das Spiel beim ersten Blick wahrgenommen? War es ansprechend und verständlich?
___________________________________________________________________________
- Hast du dich während des Spiels immer sicher gefühlt, was als nächstes zu tun ist?
Falls | oder | , warum? ____________________________________________________
- Waren die Anweisungen und Rückmeldungen (z. B. wer an der Reihe ist, ob ein Kartenpaar passt) klar und hilfreich?
Falls | oder | , warum? ____________________________________________________
- Wie empfandest du die Reaktion des Systems, nachdem du Karten aufgedeckt hast?

____________________________________________________________________________________

- Fandest du die visuellen Feedback-Elemente passend und motivierend?
Falls | oder | , warum? ___________________________________________________
- Wie hast du die Gestaltung der Benutzeroberfläche und die visuelle Darstellung der Gletscher empfunden?

_______________________________________________________________________________

_______________________________________________________________________________

_______________________________________________________________________________

- Gibt es Elemente, die dich gestört oder verwirrt haben?

_______________________________________________________________________________

_______________________________________________________________________________

_______________________________________________________________________________

- Gab es technische Schwierigkeiten (z. B. Verzögerungen beim QR-Code-Scan oder Probleme unter bestimmten Lichtverhältnissen)?

_______________________________________________________________________________

_______________________________________________________________________________

_______________________________________________________________________________

_______________________________________________________________________________

- Wie bewertest du die Stabilität und Performance des Spiels während deiner Interaktion?

_______________________________________________________________________________

_______________________________________________________________________________

_______________________________________________________________________________

_______________________________________________________________________________

- Würdest du das Spiel weiterempfehlen?
Falls | oder | , warum? ___________________________________________________
- Was könnte das Spielerlebnis noch verbessern?

_______________________________________________________________________________

_______________________________________________________________________________

_______________________________________________________________________________

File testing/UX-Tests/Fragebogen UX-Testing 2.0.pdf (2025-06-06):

# Fragebogen Gletschery

1) Wie hast du das Spiel beim ersten Blick wahrgenommen?
2) War es ansprechend und verständlich?

_________________________________________________________________________________

3) Hast du dich während des Spiels immer sicher gefühlt, was als nächstes zu tun ist?
Falls | oder | , warum? ____________________________________________________
4) Waren die Anweisungen und Rückmeldungen (z. B. wer an der Reihe ist, ob ein Kartenpaar passt) klar und hilfreich?
Falls | oder | , warum? ____________________________________________________

5) Wie empfandest du die Reaktion des Systems, nachdem du Karten aufgedeckt hast?

____________________________________________________________________________________
6) Fandest du die visuellen Feedback-Elemente passend und motivierend?
Falls | oder | , warum? ___________________________________________________
7) Wie hast du die Gestaltung der Benutzeroberfläche und die visuelle Darstellung der Gletscher empfunden?

_______________________________________________________________________________

_______________________________________________________________________________

_______________________________________________________________________________

8) Gibt es Elemente, die dich gestört oder verwirrt haben?

_______________________________________________________________________________

_______________________________________________________________________________

_______________________________________________________________________________

9) Gab es technische Schwierigkeiten (z. B. Verzögerungen beim QR-Code-Scan oder Probleme unter bestimmten Lichtverhältnissen)?

_______________________________________________________________________________

_______________________________________________________________________________

_______________________________________________________________________________

_______________________________________________________________________________

10) Wie bewertest du die Stabilität und Performance des Spiels während deiner Interaktion?

_______________________________________________________________________________

_______________________________________________________________________________

_______________________________________________________________________________

_______________________________________________________________________________

11) Hat dich das Spiel emotional angesprochen?
Falls | oder | , warum? ___________________________________________________
12) Hast du etwas Neues über Gletscher gelernt?

____________________________________________________________________________________

13) Würdest du das Spiel weiterempfehlen?
Falls | oder | , warum? ___________________________________________________
14) Was könnte das Spielerlebnis noch verbessern?

_______________________________________________________________________________

_______________________________________________________________________________

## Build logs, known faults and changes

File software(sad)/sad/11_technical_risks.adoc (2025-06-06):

[[section-technical-risks]]
== Risiken und technische Schulden
== Technische Risiken

=== 1. Risiko

==== Beschreibung
Scannen der QR-Codes stösst an technische Limitationen aufgrund der Prozessorleistung des PI.
[cols="1,2" options="header"]
|===
|Konsequenzen |Massnahmen

|Der Spielfluss ist unzuverlässig und es kommt zu Lags.
|Variablen, Bildgrösse und Scanintervalle im Auge behalten und aktiv Einfluss darauf nehmen, was wir der Software abverlangen.
|===

=== 2. Risiko
==== Beschreibung
Scannen der QR-Codes funktioniert aufgrund physikalischer Umgebungsvariablen nicht.

[cols="1,2" options="header"]
|===
|Konsequenz |Massnahme

|Unzuverlässiger bis unmöglicher Spielfluss.
|So früh wie möglich viele Variablen eliminieren und Lösungsstrategien austesten.
|===

==== Abgrenzung QR-Code Scan
[cols="1,2" options="header"]
|===
|Name |Massnahme

| Helligkeit | In der Gletschery Box wird eine LED Leiste installiert. So wird sichergestellt, dass ausreichend Licht vorhanden ist.
| Lichteinwirkung | Um Lichteinwirkung von Aussen zu minimieren wird der Kunde darüber informiert, die Spielfläche nicht unter einer Lampe oder direkt am Fenster zu platzieren.
| Spiegelungen| Die Spiegelungen sollen durch eine in die Wand eingebaute Installation der LED Leiste und einer Milchglas-Schiene verhindert werden.
| Ausrichtung der Karten| Um fehlerhafte Scans aufgrund der Rotation der Karten zu minimieren, wird ein Gitter auf der Spielfläche angebracht. So wird sichergestellt, dass alle Karten gleich ausgerichtet sind.
|===

=== 3. Risiko
==== Beschreibung
Hardware wird nicht fertig oder entspricht nicht den Anforderungen.
[cols="1,2" options="header"]
|===
|Konsequenzen |Massnahmen

|Unzuverlässiger Input und Output für den User.
|Frühes Testen der Komponenten, sodass genug Zeit bleibt um zu reagieren.
|===

=== 4. Risiko
==== Beschreibung
Software wird nicht fertig oder entspricht nicht den Anforderungen.
[cols="1,2" options="header"]
|===
|Konsequenzen |Massnahmen

|Lags, unzuverlässiger Spielfluss und unzuverlässiger Input/Output für User.
|Fokus auf Hauptfeatures. Frühes Testen der Software, sodass genug Zeit bleibt um zu reagieren.
|===

=== 5. Risiko
==== Beschreibung
Keine passenden Bilder gefunden oder Nutzungsrechte werden nicht zugesagt.

|===
|Konsequenzen |Massnahmen

|Visuelle Umsetzung der Produktvision kann nicht umgesetzt werden.
|Frühes Aussuchen der Inhalte und Abklären der Nutzungsrechte.
|===

=== 6. Risiko
==== Beschreibung
Verlust von Code oder Dokumentation.
[cols="1,2" options="header"]
|===
|Konsequenzen |Massnahmen

|Arbeit geht verloren und wir werden im Projektfortschritt zurückgeworfen.
|Wir arbeiten mit Gitlab. Auf dem main-Branch befindet sich immer die momentan funktionale Version. In Feature Branches wird am Projekt gearbeitet und nach Bestehen der Tests werden diese mit dem main gemerged. Zusätzlich klonen drei Teammitglieder regelmässig das gesamte Repository, damit immer eine lokale Kopie vorhanden ist.
|===

=== 7. Risiko
==== Beschreibung
Defekte treten kurz vor der Abgabe auf.
[cols="1,2" options="header"]
|===
|Konsequenzen |Massnahmen

|Es bleibt nicht genügend Zeit, um das Produkt wieder auf einen übergabefähigen Stand zu bringen.
|Regelmässiges Testen und betreiben der Hardware.
|===

== Personelle Risiken

=== 8. Risiko
==== Beschreibung
Streit im Team
[cols="1,2" options="header"]
|===
|Konsequenzen |Massnahmen

|Moral und Motivation gehen verloren. Da wir ein kleines Team sind, entspräche dies einem erheblichen Wegfall von produktiver Zeit.
|Offene Kommunikation, Kultur von häufigem Feedback, sodass dieses auch inhaltlich und nicht persönlich verstanden wird. Individuelles Empfinden akzeptieren, verstehen und managen.

|===

=== 9. Risiko
==== Beschreibung
Personelle Ausfälle
[cols="1,2" options="header"]
|===
|Konsequenzen |Massnahmen

|Da wir ein kleines Team sind, entspräche dies einem erheblichen Wegfall von produktiver Zeit.
|Stetiger Wissenstransfer. Geleistete Arbeit wird wöchentlich kommuniziert und Ergebnisse für alle erreichbar abgelegt.

|===

== Organisatorische Risiken

=== 10. Risiko
==== Beschreibung
Zentrale Deliverables gehen vergessen.
[cols="1,2" options="header"]
|===
|Konsequenzen |Massnahmen

|Unzufriedener Kunde und Jury. Tadel sowie Notenabzug.
|Gute Planung, Controlling der Planung und proaktiv Feedback bei Teamcoach einholen.
|===

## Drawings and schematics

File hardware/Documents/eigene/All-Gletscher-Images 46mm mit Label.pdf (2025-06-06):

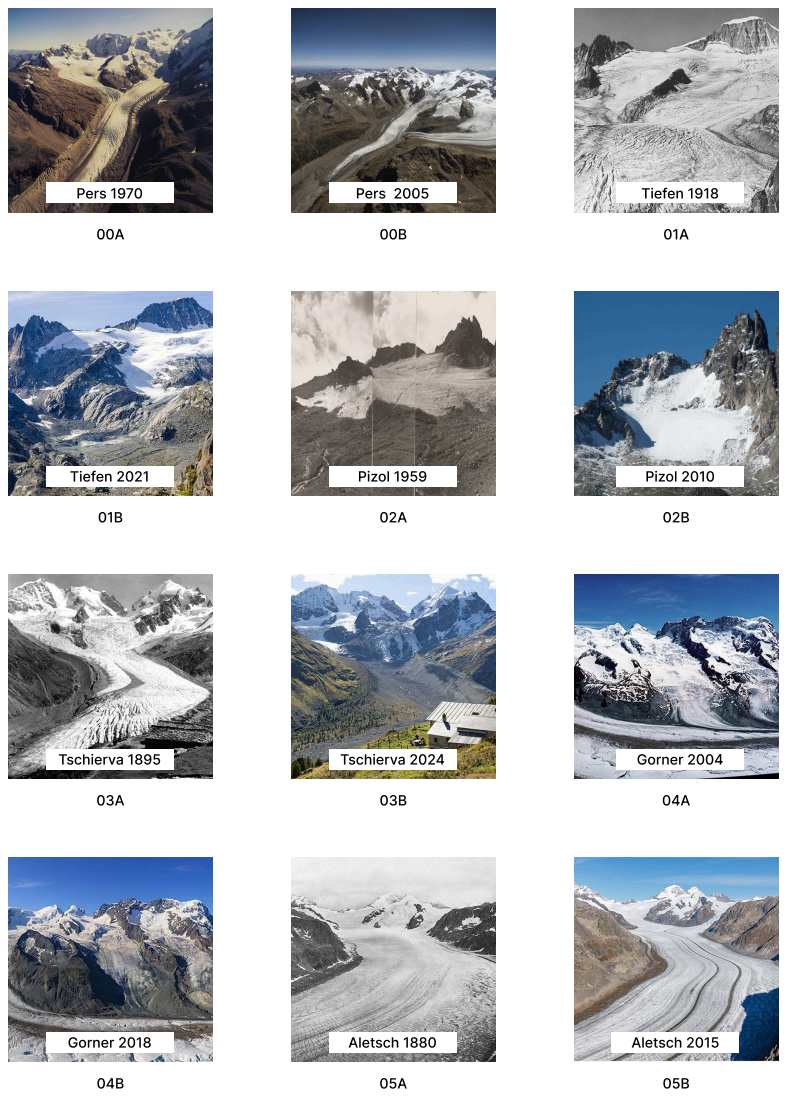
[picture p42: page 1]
Tiefen 2021; Pers 1970; Pers 2005; Pizol 2010; Tschierva 2024; Gorner 2004; Gorner 2018; Aletsch 1880; Aletsch 2015; Tschierva 1895; Pizol 1959; Tiefen 1918

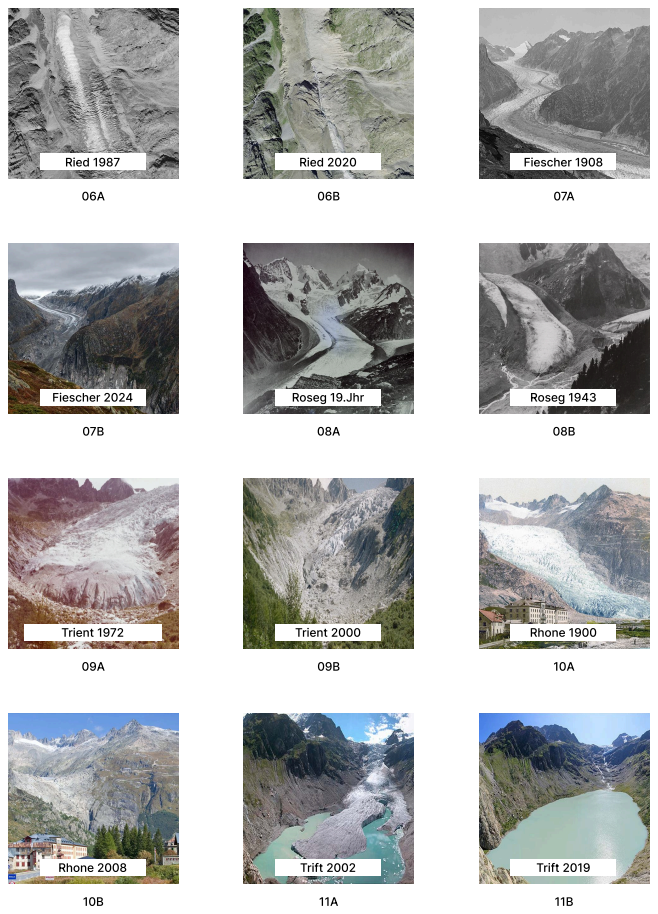
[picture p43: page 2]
Fiescher 1908; Fiescher 2024; Trient 1972; Trient 2000; Rhone 1900; Rhone 2008; Trift 2002; Trift 2019; Roseg 19.Jhr; Roseg 1943; Ried 1987; Ried 2020
